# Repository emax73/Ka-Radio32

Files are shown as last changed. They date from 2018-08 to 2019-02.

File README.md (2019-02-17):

## STATE
Release 1.8 Stable

Works on any esp32 board.  
See the boards directory for a list of pre-configured boards.
- The esp32 adds the output on the internal dac or with i2s to an external dac but only mp3 stations can be played.  
Adding a vs1053 board, all stations can be played.  
Compatible with esp8266 KaRadio addons.  
- Serial or telnet commands : https://github.com/karawin/Ka-Radio32/blob/master/Interface.md

### New
A new android application is born  
  
- KaRadio Remote Control by Vassilis Serasidis on google Play.

It is an easy and fast WiFi remote control for your KaRadio or KaRadio32 hardware.  
With this android app you can select the WebRadio station you want to play, set the volume and get the station information such as Station name, Genre, Bit rate, Meta data and more.   
Found it at
https://play.google.com/store/apps/details?id=com.serasidis.karadio.rc

Thanks Vassilis.
## Added features from KaRadio
Work with i2s, internal DAC or a vs1053.  
Output mode set in Setting panel on web page of KaraDio32 :

- I2S for connection to an external DAC
- I2SMERUS to connect a merus amplifier
- DAC to use the built in DAC of the esp32
- PDM to output a PDM (Pulse Density Modulation) stream
- VS1053 to connect to a vs1053 board, I2S output of the vs1053 enabled.
- all VS1053 tones control
- AAC decoding on I2S with a wrover cpu (4mB of external psram). Mp3 only on I2S with a wroom cpu.

### Others features :

- Interfaces available on serial, telnet and html
- up to 255 editable stations.
- Handles bitrates up to 320 kbps.
- Stations can be saved and restored from html in and from a file.
- Hardware configuration file to adapt the standard delivery to all boards and addons you need.
- all configurable parameters automatically saved.
- mDNS support.
- wrover esp32 support. About 10 seconds of buffering, and soon A2DP support (sink and source)
- Time Zone Offset support.
- Latin, Cyrillic and Greek support on screen.
- 28 types of lcd or oled  B/W or Color supported.
- Programmable lcd backlight off timer.
- Touch screen if the hardware supports it.
- Two joysticks (set of two adc buttons), one for volume, one for stations.
- Two max  rotary encoders. One for volume priority, one for station change priority.
- Two max set of 3 buttons. One for volume priority, one for station change priority.
- Rotary encoder and set of buttons support included. Common functions : play/stop, volume, station change, date time display.
- ADC keyboard with 6 buttons.
- Date format DD:MM:YYYY or MM:DD:YYYY .
- Remote IR support integrated. Nec protocol only.
- Two configurable access points .
- OTA (Over The Air) update of the software.
- Uses a 40 kB (I2S), 50 kB (vs1053) or 420 Kb (wrover) queue to provide smooth playback.
- many more configurable parameters. See [Interfaces document](Interface.md )  

## Configure the hardware and IR codes
If the default configuration doesn't fit your needs, you can externally configure the software to fit your hardware and peripherals to suit your needs.  
The configuration file is to be flashed only one time. After, the standard delivery will become compatible with your hardware gpio use and peripherals configuration. A future standard OTA will automatically works for your configuration.  
See : [Hardware configuration partition](HardwareConfig.md)

## Build your own
To build your own release if you want to do some improvments, you must install the idf https://github.com/espressif/esp-idf and the toolchain.

To flash all build output, run 'make flash' or :

```
python /home/yourhome/esp/esp-idf/components/esptool_py/esptool/esptool.py \
   --chip esp32 --port com5 --baud 460800 --before default_reset \
   --after hard_reset write_flash -u --flash_mode dio \
   --flash_freq 40m --flash_size detect \
   0x1000 /home/yourhome/esp/Ka-Radio32/build/bootloader/bootloader.bin \
   0x10000 /home/yourhome/esp/Ka-Radio32/build/KaRadio32.bin \
   0x8000 /home/yourhome/esp/Ka-Radio32/build/partitions.bin
```
### GPIO Definition 
The default configuration is given below. It includes an encoder, an IR remote and a LCD or OLED.  
To add or edit GPIO definitions and add or remove some devices, you may need a hardware configuration file. Some examples are in the boards directory.  
See the file main/include/gpio.h and main/include/addon.h

```
//--------------------------------------//
// Define GPIO used in KaRadio32        //
// if no external configuration is used //
//--------------------------------------//
// Compatible ESP32 ADB
// https://www.tindie.com/products/microwavemont/esp32-audio-developing-board-esp32-adb/
// Default value, can be superseeded by the hardware partition.

// Must be HSPI or VSPI

#define KSPI VSPI_HOST

// KSPI pins of the SPI bus
//-------------------------
#define PIN_NUM_MISO GPIO_NUM_19 	// Master Input, Slave Output
#define PIN_NUM_MOSI GPIO_NUM_23	// Master Output, Slave Input   Named Data or SDA or D1 for oled
#define PIN_NUM_CLK  GPIO_NUM_18 	// Master clock  Named SCL or SCK or D0 for oled

// status led if any.
//------------------- 
// Set the right one with command sys.led
// GPIO can be changed with command sys.ledgpio("x")
#define GPIO_LED	GPIO_NUM_4		// Flashing led or Playing led

// gpio of the vs1053
//-------------------
#define PIN_NUM_XCS  GPIO_NUM_32
#define PIN_NUM_RST  GPIO_NUM_12 
#define PIN_NUM_XDCS GPIO_NUM_33
#define PIN_NUM_DREQ GPIO_NUM_34
// + KSPI pins

// Encoder knob
//-------------
#define PIN_ENC0_A   GPIO_NUM_16	//16	// 255 if encoder not used
#define PIN_ENC0_B   GPIO_NUM_17	//17	// DT
#define PIN_ENC0_BTN GPIO_NUM_5		//5// SW
#define PIN_ENC1_A   GPIO_NONE		// 255 if encoder not used
#define PIN_ENC1_B   GPIO_NONE		// DT
#define PIN_ENC1_BTN GPIO_NONE		// SW

// 3 Buttons
//-------------
#define PIN_BTN0_A   GPIO_NONE		
#define PIN_BTN0_B   GPIO_NONE		
#define PIN_BTN0_C   GPIO_NONE		
#define PIN_BTN1_A   GPIO_NONE		
#define PIN_BTN1_B   GPIO_NONE		
#define PIN_BTN1_C 	 GPIO_NONE		

// Joystick (2 buttons emulation on ADC)
//--------------------------------------
#define PIN_JOY_0	GPIO_NONE
#define PIN_JOY_1	GPIO_NONE

// I2C lcd (and rda5807 if lcd is i2c or LCD_NONE)
//------------------------------------------------
#define PIN_I2C_SCL GPIO_NUM_14
#define PIN_I2C_SDA GPIO_NUM_13
#define PIN_I2C_RST	GPIO_NUM_2		// or not used

// SPI lcd
//---------
#define PIN_LCD_CS	GPIO_NUM_13		//CS
#define PIN_LCD_A0	GPIO_NUM_14		//A0 or D/C
#define PIN_LCD_RST	GPIO_NUM_2		//Reset RES RST or not used
// KSPI pins +

// IR Signal
//-----------
#define PIN_IR_SIGNAL GPIO_NUM_21	// Remote IR source

// I2S DAC or PDM output
//-----------------------
#define PIN_I2S_LRCK GPIO_NUM_25	// or Channel1
#define PIN_I2S_BCLK GPIO_NUM_26	// or channel2
#define PIN_I2S_DATA GPIO_NUM_22	//  

// ADC for keyboard buttons
#define PIN_ADC	GPIO_NONE	//GPIO_NUM_32 TO GPIO_NUM_39 or GPIO_NONE if not used.

// LCD backlight control
#define PIN_LCD_BACKLIGHT	GPIO_NONE // the gpio to be used in custom.c 

// touch screen  T_DO is MISO, T_DIN is MOSI, T_CLK is CLk of the spi bus
#define PIN_TOUCH_CS	GPIO_NONE //Chip select T_CS

```
### LCD or oled declaration  
You can configure the kind of display used in your configuration with the command  
'sys.lcd("x")' with x:  
  
```
#define LCD_NONE		255

// Black&White
//I2C
#define LCD_I2C_SH1106		0 //128X64
#define LCD_I2C_SSD1306		1 //128X64
#define LCD_I2C_SSD1309		2 //128X64
#define LCD_I2C_SSD1325 	3 //128X64
#define LCD_I2C_SSD1306NN	4 //128X64
#define LCD_I2C_SSD1309NN	5 //128X64
#define LCD_I2C_SSD1306UN	6 //128x32

//SPI
#define LCD_SPI_SSD1306 		64 //128X32 (LCD_SPI =0x40)
#define LCD_SPI_SSD1309 		65 //128X64
#define LCD_SPI_ST7565_ZOLEN	66 //128X64
#define LCD_SPI_SSD1322_NHD		67 //256X64
#define LCD_SPI_IL3820_V2		68 //296X128
#define LCD_SPI_SSD1607			69 //200X200
#define LCD_SPI_LS013B7DH03		70 //128X128
#define LCD_SPI_SSD1306NN 		71 //128X64
#define LCD_SPI_SSD1309NN 		72 //128X64
#define LCD_SPI_ST7920 			73 //128X64

// Colors
#define LCD_SPI_ST7735			192 // 128x160  (LCD_COLOR|LCD_SPI =0xC0)
#define LCD_SPI_SSD1351			193 // 128x128
#define LCD_SPI_ILI9341			194 // 240x320
#define LCD_SPI_ILI9163			195 // 128x128
#define LCD_SPI_PCF8833			196 // 132x132
#define LCD_SPI_SSD1331			197 // 96x64
#define LCD_SPI_SEPS225			198 // 96x64
#define LCD_SPI_ST7789V			199 // 240x320
#define LCD_SPI_ST7735S			200 // 128x128
#define LCD_SPI_ST7735L			201 // 80x160
#define LCD_SPI_ST7735W			202 // 128x160 shifted 2+1
```

## First use
- If the access point of your router is not known, the webradio initialize itself as an AP. Connect the wifi of your computer to the ssid "WifiKaRadio",  
- Browse to 192.168.4.1 to display the page, got to "setting" "Wifi" and configure your ssid ap, the password if any, the wanted IP or use dhcp if you know how to retrieve the dhcp given ip (terminal or scan of the network).
- In the gateway field, enter the ip address of your router.
- Validate. The equipment restart to the new configuration. Connect your wifi to your AP and browse to the ip given in configuration.
- Congratulation, you can edit your own station list. Don't forget to save your stations list in case of problem or for new equipments.
- if the AP is already know by the esp32, the default ip is given by dhcp.
- a sample of stations list is on http://karadio.karawin.fr/WebStations.txt . Can be uploaded via the web page.        

To flash your KaRadio32 without generating it, you will need the files in the binaries directory.

The tool to use is here :  
http://espressif.com/en/support/download/other-tools  
(change the security of the installation directory to permit all)

See the image at :  
http://karadio.karawin.fr/karawin32Flash.jpg

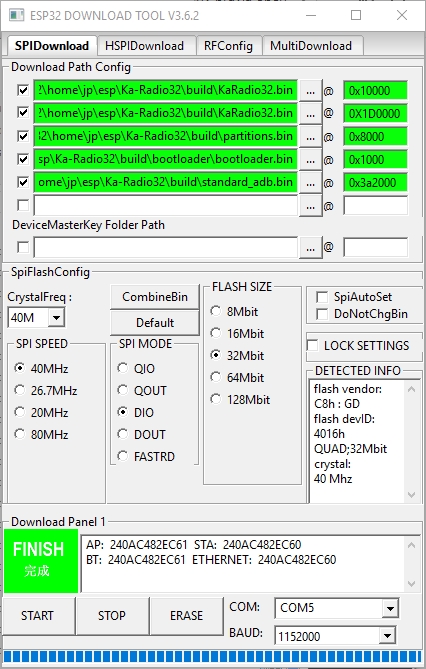
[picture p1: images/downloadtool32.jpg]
Screenshoot of download tool


### The scheme from tomasf71 : 
Just an example of a realization.  
 
Scheme

## Audio output

In the Setting panel on the webpage of KaraDio32 you can set the desired output method for audio.

For output on a simple speaker or a general analog amplifier :

- DAC to use the built in DAC of the esp32
- PDM to output a PDM (Pulse Density Modulation) stream. Wiki on PDM : https://en.wikipedia.org/wiki/Pulse-density_modulation

For output via addional I2S or VS1053 hardware :

- I2S for connection to ac external DAC
- I2SMERUS to connect a merus amplifier
- VS1053 to connect to a vs1053 board.

### Connecting a speaker, earphone or amplifier with DAC or PDM setting
You can connect the GPIO25 (left audio channel), GPIO26 (right audio channel) and Ground directly to a small loudspeaker, a simple earphone (like from an mp3 player) or the input of an analog amplifier. The quality is less perfect than using an I2S or VS1053 board, bit it is very simple hardware-wise.

Connect like this :

```
                         +------------------------------------+
ESP32-GPIO25 (left) -----+speaker/earphone/analog-amp (left)   +-----+
                         +------------------------------------+      |
                                                                     |
                         +------------------------------------+      |
ESP32-GPIO26 (right) ----+speaker/earphone/analog-amp (right  +------+
                         +------------------------------------+      |
                                                                     |
ESP32-GROUND --------------------------------------------------------+
```

### Reducing the analog output level
If the audio signal level is too high for your speaker, earphone or amplifier you can add a potentiometer to decrease the level. Connect the potentiometer like this (only pictured for 1 audio channel, for stereo you need 2 potentiometers or a stereo-potmeter.

```
                                     +--------------------------------------+
ESP32-GPIO25 (left) -------+   +-----+speaker/earphone/analog-amp (left)    +------+
                          +-+  |     +--------------------------------------+      |
                          +P+  |                                                   |
                          +o+--+                                                   |
                          +t+                                                      |
                          +++                                                      |
                           |                                                       |
ESP32-GROUND --------------+-------------------------------------------------------+
```

### Improving the audio quality with a filter
An analog DAC signal always has some noise that may cause some distortion on the audio output, especially on low volume passages in the sound. This noise can be decreased with a low-pass filter. The digital PDM signal needs allways low pass filter to convert the digital signal to an analog signal. Fortunately the speaker and earphone acts as a low pass filter, although not in a perfect way.

You can improve the analog signal with an external low-pass filter. A simple low-pass RC filter can be find on the internet, f.i. here :  
http://www.pavouk.org/hw/usbdac/en_index.html.

## Radio streams
If Karadio32 is configured to use ADC, PDM or I2S output (to an external dac) it can play audio streams in mp3 format. Other formats like AAC and WMV require too much dynamic memories and can not be played this way.

When you want to play other formats you add an external VS1053 decoder to Karadio. Details on the features of this decoder can be found here : http://www.vlsi.fi/en/products/vs1053.html

Many boards can be found at :  
https://www.aliexpress.com/wholesale?catId=0&initiative_id=SB_20180113141636&SearchText=vs1053b

## Handling streaming errors
Normally a radio station is played without interruption.

But when a connection to the server of the radio station is (temporarily) disrupted (due to internet problems or server problems) Karadio behaves as follows:

- Playing of the radio stream stops, after a short while Karadio retries to relaunch the connection to the radio stream.
- If the relaunch of the connection fails again, the webpage of Karadio then shows “invalid address” and goes into the stop state. If you have a display connected to Karadio it will then show the Date, Time and IP address.
- You can try to relaunch the connection manually by pressing “play” on the Karadio webpage, or resetting the ESP32.
- If the wifi is disconnected, the esp is rebooted.

## List of sources and components adapted for KaRadio32

- The Espressif IDF : https://github.com/espressif/esp-idf
- The Esp8266 KaRadio : https://hackaday.io/project/11570-wifi-webradio-with-esp8266-and-vs1053  
- The KaRadio addons : https://github.com/karawin/karadio-addons
- Webradio for ESP-ADB module : https://github.com/kodera2t/ESP32_OLED_webradio
- Webradio with the MP3 decoder software : https://github.com/MrBuddyCasino/ESP32_MP3_Decoder
- Black/White oled lcd library : https://github.com/olikraus/u8g2
- Color LCD library : https://github.com/olikraus/ucglib
- u8g2 Hal for esp32 : https://github.com/nkolban/esp32-snippets/tree/master/hardware/displays/U8G2
- Encoder : https://github.com/soligen2010/encoder

Encoder an Oled display

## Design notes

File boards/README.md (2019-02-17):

# BOARDS Description

This directory contains some samples of common boards found on the market.  
They are to be modified to your needs and peripheral connected.  

standard_adb.csv is the default description of the gpio used when no hardware partition is flashed.

standard_psram.bin  is the default description for a wrover cpu

standard_touch.bin  is the default description for a wroom cpu with a touch screen

lolin32pro.csv is adapted to a wrover lolin pro or ttgo board.  

ttgot8.csv, ttgotm.csv,ttgov4.csv are for the correspondant boards.

odroid.csv is for the Odroid Go device. See https://github.com/pepelnyy/KaRadio32-on-ODROID-GO

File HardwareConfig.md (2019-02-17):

# Hardware configuration partition

Version 1.5 and up of KaRadio32 allows you to configure gpio's and two custom IR keys per action.  
This allows you to take advantage of the standard software even if your port configuration and/or your remote control are not the same.  
The configuration must be specified in a csv file.  
A template is given by the pattern.csv file
The default configuration of the current software is in the standard_adb.csv file.  
A csv file is interpreted by an utility to generate a bin file that must be flashed at address 0x3a2000 only one time per esp32

---------------
1/ Prerequisite
---------------
Toolchain Setup
--------------------
The quick setup is to download the Windows all-in-one toolchain & MSYS2 zip file from dl.espressif.com:

https://dl.espressif.com/.../esp32_win32_msys2...

- Unzip the zip file to C:\ (or some other location, but this guide assumes C:\) and it will create an msys32 directory with a pre-prepared environment.
- Open a MSYS2 MINGW32 terminal window by running C:\msys32\mingw32.exe. Create a directory named "esp" that is a default location to develop ESP32 applications. To do so, run the following shell command: mkdir -p ~/esp
- Type : cd ~/esp to move the newly created directory. If there are no error messages you are done with this step.
- Type : git clone -b v3.1.2 --recursive https://github.com/espressif/esp-idf.git
- Create a new script file in C:/msys32/etc/profile.d/ directory. Name it export_idf_path.sh
Identify the path to ESP-IDF directory. It is specific to your system configuration and may look something like C:\msys32\home\"your-user-name"\esp\esp-idf
Add this to the above created script file: export IDF_PATH="C:/msys32/home/"your-user-name/esp/esp-idf"
Save the script file.
- Close MSYS2 window and open it again. Check if IDF_PATH is set, by typing: printenv IDF_PATH
The path previously entered in the script file should be printed out.
- Type : pip install --upgrade setuptools  
- Type : python -m pip install --upgrade pip
- Type : pip install future
- Type : pacman -S mingw-w64-i686-python2-cryptography
- Type : pip install cryptography
- Place the Ka-Radio32-master files in "your-user-name"/esp folder. Find it at https://github.com/karawin/Ka-Radio32
---
  
Second  make sure you have an updated partitions.bin file.  
Find it at "your-user-name"/esp/Ka-Radio32/tree/master/binaries  
This file contains the system partitions:
```
$ make partition_table
Toolchain path: /opt/xtensa-esp32-elf/bin/xtensa-esp32-elf-gcc
Toolchain version: crosstool-ng-1.22.0-80-g6c4433a5
Compiler version: 5.2.0
Python requirements from C:/msys32/home/jp/esp/esp-idf/requirements.txt are satisfied.
Partition table binary generated. Contents:
*******************************************************************************
# Espressif ESP32 Partition Table
# Name, Type, SubType, Offset, Size, Flags
nvs,data,nvs,0x9000,16K,
otadata,data,ota,0xd000,8K,
phy_init,data,phy,0xf000,4K,
ota_0,app,ota_0,0x10000,1792K,
ota_1,app,ota_1,0x1d0000,1792K,
device,64,0,0x390000,4K,
stations,65,0,0x391000,64K,
device1,66,0,0x3a1000,4K,
hardware,data,nvs,0x3a2000,8K,
*******************************************************************************
Partition flashing command:
python /home/jp/esp/esp-idf/components/esptool_py/esptool/esptool.py --chip esp32 --port com5 --baud 460800 --before default_reset --after hard_reset write_flash 0x8000 /home/jp/esp/Ka-Radio32/build/partitions.bin
************************************************ *****************************
```
Compared to an old version, it adds the declaration of the partition "hardware" which interests us.

Rename the pattern.csv file with the name of your c
ard, for example lolin32.csv  
Beware: not comment line or empty line allowed in a csv file.

#### WARNING:
The declaration of gpio's is a not so easy task.  
Any error results in an incorrect start of the software.  
If the software does not start properly, please check your values.  
A common mistake is to declare the same number for two functions.  
See the log on the serial interface.

------------------------------------
2/ Definition of gpio's and options
------------------------------------
Edit the csv file to enter your gpio and options definitions.  
See gpio.h for the default values if missing in the csv file.  
Only modify the lines beginning with P_ or O_ by modifying only the last number.  
for example:  
P_MISO, data,u8,19  
Change 19 to the desired number.  
Do this for all P_ and O_lines.  
Never change the string "P_XXXX, data,u8,"  
A value base 10 is mandatory for each P_.  

## GPIO
Definition of the lines in csv  
- **SPI Bus:**  
K_SPI		Select the used spi : 1: HSPI, 2: VSPI  
P_MISO		Master Input, Slave Output    
P_MOSI		Master Output, Slave Input   Named Data or SDA or D1 for oled  
P_CLK		Master clock  Named SCL or SCK or D0 for oled  
- **VS1053B:**  
P_XCS			XCS  
P_RST			RST  
P_XDCS			XDCS  
P_DREQ			P_DREQ  
- **ENCODERS 0 & 1:**  
P_ENC0_A			pin A clk  
P_ENC0_B			pin B Data  
P_ENC0_BTN			pin SW  
P_ENC1_A			pin A clk  
P_ENC1_B			pin B Data  
P_ENC1_BTN			pin SW  
- **BUTTONS PANEL 0 & 1** of three buttons (switch to gnd):  
P_BTN0_A		click:start/stop, double click:toggle, help: station  
P_BTN0_B		click: +  
P_BTN0_C		click: -  
P_BTN1_A		start/stop, toggle, volume  
P_BTN1_B		+  
P_BTN1_C		-  
- **JOYSTICK 0 & 1**  
P_JOY_0			Volume control  	
P_JOY_1		
- **Bus I2C (Oled & Lcd):**  
P_I2C_SCL		SCL or SCK  
P_I2C_SDA		SDA  
P_I2C_RST		RST if any  
- **LCD on SPI bus:**  
P_LCD_CS		CS  
P_LCD_A0		A0 or D/C or DC  
P_LCD_RST		RST or RES  
- **Infrared remote:**  
P_IR_SIGNAL		ir Y Signal  
- **I2S bus:**  
P_I2S_LRCK		LRCK  
P_I2S_BCLK		BCLK  
P_I2S_DATA		DATA  
- **ADC keyboard:**  
P_ADC_KBD			gpio32 to 39  or 255 if not used. 
- **LCD Backlight:**   
P_BACKLIGHT		GPIO of the hardware device.
- **TOUCH SCREEN:**  
P_TOUCH_CS		GPIO of the t_cs pin of the touch or 255 if no screen  
  Other pins are t_clk, t_din, t_do respectively the spi clk, mosi, miso. T_irq is not used.  
- **LED GPIO**  
P_LED_GPIO		GPIO of the status led  

## OPTIONS
- **LCD CONTROL**  
P_LCD_TYPE		Type of lcd (see [addon.h](https://github.com/karawin/Ka-Radio32/blob/master/main/include/addon.h) file).  
P_LCD_ROTA		Control the rotation of the LCD, 0 no rotation, 1: rotation.  
O_LCD_OUT 		The tempo to light off the screen in seconds. 0 is no tempo.   
O_DDMM_FLAG		The format of the date to display 0:MMDD, 1:DDMM.  
-------------------
## Special cases:
-------------------
### GPIO
- GPIOs 34 to 39 are input only pins.  
These pins don’t have internal pull-ups or pull-down resistors.  
They can’t be used as outputs, so use these pins only as inputs or ADC usage.  
- Digital to Analog Converter (DAC)  
There are 2 x 8 bits DAC channels on the ESP32 to convert digital signals into analog voltage signal outputs.  
These are the DAC channels:  
-    DAC1 (GPIO25)  
-    DAC2 (GPIO26)
### SPI bus

K_SPI,data,u8,2  
- 1 is the spi HSPI_HOST  
- 2 is the spi VSPI_HOST (default)  
   The spi bus is initialized in any case. It used for the vs1053 and/or the LCD if needed.  
   Prefered gpio for the spi bus (IOMUX):  
   HSPI: SCLK=14, MISO=12, MOSI=13  
   VSPI: SCLK=18, MISO=19, MOSI=23  

### Encoders

Two encoders maximun are supported, each with different actions:  
Encoder0: the volume control and stations change when pushed and held,  
Encoder1: the station control and volume change when pushed and held.  

If P_ENC0_A = 255 the encoder (P_ENC0_A, P_ENC0_B, P_ENC0_BTN) is disabled (not used, the gpio's may be reused elsewhere).    
If P_ENC1_A = 255 the encoder (P_ENC1_A, P_ENC1_B, P_ENC1_BTN) is disabled (not used, the gpio's may be reused elsewhere).  
If If P_ENC0_A is not 255 and P_ENC0_BTN = 255, the push button is disabled.  
If If P_ENC1_A is not 255 and P_ENC1_BTN = 255, the push button is disabled.  

### Buttons
Two set of three buttons can be configured in place or with encoder(s). The only limit is the available gpio's.  
Each set has functions equivalent to Encoder0 and Encoder1:  
click on button A: Start/Stop playing  
click on button B and C: volume down and up for set 0 (P_BTN0), Station down and up for set 1 (P_BTN1)  
held on button A: click on button B and C: volume down and up for set 1 (P_BTN1), Station down and up for set 0 (P_BTN0)  

If a set is not used, P_BTNx_A must be set to 255. In this case P_BTNx_B P_BTNx_C are disabled too.

### Joystick
A joystick is a set of two buttons but both cannot be pushed at the same time.  
The GPIO must be an ADC one, i.e gpio32 to 39  or 255 if not used.   
Joystick 0  controls the volume,  
Joystick 1 controls the station choice.  
Botton 0 is 3.3 V  
Button 1 is 3.3/2 V  
An example of joystick:  
Screenshoot of joystick

### I2C
If I2C is not used (ie no lcd or spi lcd) the gpio of the i2C can be reused elsewhere.  
To disable I2C even a I2C LCD is used: P_I2S_LRCK	and/or P_I2S_BCLK	must be set to 255  

### VS1053b
If not used P_XCS must be set to 255. Gpio of P_RST P_XDCS P_DREQ may be reused elsewhere.  

### IR
If IR remote control is not used P_IR_SIGNAL must be set to 255

### ADC keyboard
If the ADC keyboard is missing, set P_ADC  to 255.  
GPIO pin must be gpio32 to 39  or 255 if not used.   
Compatible with https://github.com/karawin/Ka-Radio/blob/master/Hardware/controles.pdf and the one found at https://www.drive2.ru/b/487463808323813881/  
The stop button is replaced with "Toggle Time/Infos" and "start replaced with "Start/Stop"  
The ESP32 ADC can be sensitive to noise leading to large discrepancies in ADC readings. To minimize noise, users may connect a 0.1uF capacitor to the ADC input pad in use

### Lcd backlight
Thanks to Vadim Polyakovsky:
> A small optional schematics update which allows to switch LCD backlight on and off in case of battery powered KaRadio. The switching off timeout in x sec could be defined by sys.lcdout("x") terminal command. The display and its' backlight will wake up automatically in case of new meta, encoder or IR event. This way the battery life on one charge will be extended. Obviously not needed for OLED displays and wall plug power socket operation. A software support is done by Jean-Pierre in the new custom.c file. A GPIO number could be chosen among not used ones and defined respectively. Enjoy!
 
This external device turns off the LCD backlight in addition to the screen clear.    
Usefull if a battery is used.  
If the hardware device is missing, set it to 255

Screenshoot of backlight  

### TOUCH SCREEN
P_TOUCH_CS  of the t_cs pin of the touch or 255 if no screen.  
Other pins are t_clk, t_din, t_do respectively the spi clk, mosi, miso. T_irq is not used.  
The screen must be calibrated with the command sys.cali[brate]  
The screen is divided in 5 zones:  
- Center: Start/Stop
- Top: Volume+
- Bottom: Volume-
- Left: Station-
- Bottom: Station+

### OPTIONS
If any options value is 255, the values defined by sys. command are unchanged.  
If a sys. command changes the value in csv, the internal flashed bin of the csv is updated.  
As long  the original bin is not flashed again, the internal value apply. 

---------------------
3/ IR key definitions
---------------------
If you use a remote control with different codes from the default ones, you can give your codes by key.
Two codes per key are possible:

For example for the K_OK key  
K_OK, data, string, 0xFF0040 0xFF0040  
or  
K_OK, data, string, 0xFF0040  
if you only have one code per key.  
or  
K_OK, data, string,  
if no code is given for the OK key  

Never change "K_XXXX,data,string,"  

Reminder: to see the code of a key on your remote control, change the log level to sys.logi  
Press a key and see the log. You will see something like that:  
I (1204396) addon: IR event: Channel: 0, ADDR: ff00, CMD: bf40 = FF0040, REPEAT: 0  
Where FF0040 is the 0xFF0040 code needed.  
```
The keys and actions are:
K_UP  		Change to next Station 
K_LEFT		Volume Down -5
K_OK		Toggle play/Stop
K_RIGHT		Volume up +5
K_DOWN		Change to previous station
K_0			Enter number of the wanted station
K_1			Enter number of the wanted station
K_2			Enter number of the wanted station
K_3			Enter number of the wanted station
K_4			Enter number of the wanted station
K_5			Enter number of the wanted station
K_6			Enter number of the wanted station
K_7			Enter number of the wanted station
K_8			Enter number of the wanted station
K_9			Enter number of the wanted station
K_STAR		Play
K_DIESE		Stop
K_INFO		Toggle time/info display
```
No comment is allowed in this csv file.  
Save the csv file.

------------------------
4/ Generating the bin
------------------------
Some samples are in the boards directory.   

Build the bin file
------------------
1. Place the Ka-Radio32-master files in "your-user-name"/esp folder
2. Place your modified csv file in the Ka-Radio32-master/boards folder

3. Return to the msys32 window and navigate to the Ka-Radio32-master/boards folder

4. Start the command : ./nvs_partition_generator.sh yourname[.csv] to generate build/yourname.bin

Result :   
MINGW32 ~/esp/Ka-Radio32-master/boards  
$ ./nvs_partition_generator.sh modified_adb  
python ./nvs_partition_gen.py modified_adb.csv build/modified_adb.bin 0x2000  
done  

------------
5/ Flash the bin
------------
With ESP DOWNLOAD TOOL   
Screenshoot of download tool

or esptool.py command at address 0x3a2000  

It seems that there is a problem with this ESP DOWNLOAD TOOL for flashing the bin alone.  
In case of problem, flash it with another bin (bootloader.bin or KaRadio32.bin) 
 
This binary is to flash one time and on each modification of the csv.

Now you can enjoy the standart OTA. No needs to generate your own KaRadio32.bin.

JP 2018

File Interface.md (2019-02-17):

# Interfaces of KaRadio and KaRadio32
____________________________________

## HTML interface for the Wifi Webradio
Any browser or wget can be used to send basic commands to the webradio.  
A command format is http://yourip/?command[&command]  
If a command return some informations, it must be the last of the list or alone.

## Commands:  
- version		: return 'Release: x.x, Revision: x'  
- infos			: return   
				vol: 46						:the current volume  
				num: 240						:the current station number  
				stn: Hotmix 80					:the name of the current station  
				tit: BANANARAMA - Venus 		:the title of the son playing  
				sts: 1							:the state of the player: 0 stopped, 1:   playing.
- list=xxx		: return the name of the station xxx (0 to 254)				
- stop			: stop playing the current station.
- start			: start playing the current station.
- next			: play the next station
- prev			: play the previous station
- play=xxx		: with xxx from 0 to 254  play the station xxx
- volume=xxx		: with xxx from 0 to 254  change the volume to xxx
- uart			: uart baudrate at 115200 not saved on next reset
- instant="http://your url" : instant play a site  
Example: http://192.168.1.253/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"  
the url must begin with http:// and be surrounded by " and no space char allowed.

Volume may be combined with other command.  
Example: 192.168.1.253/?volume=50&play=128&infos

Reminder: the url without parameter is the full web interface.

-------------------------------------------------
## Serial ot telnet interface for the Wifi Webradio

The serial inteface can be used to receive events from the webradio and to send commands to it.  
The telnet interface is reached by the port 23.  
The serial interface adds the logs output of the tasks.  

Example of indications received: 
```
##CLI.STOPPED# from playStationInt
##CLI.NAMESET#: 88 Public Domain Classical - Swiss Internet Radio
##CLI.URLSET#: 82.197.165.137
##CLI.PATHSET#: /
##CLI.PORTSET#: 80
##CLI.OVOLSET#: 0
##CLI.VOL#: 110
##CLI.ICY0#: Public Domain Classical - Swiss Internet Radio - Shoutcast Streaming Technology by www.init7.net
##CLI.ICY1#: <BR>This stream requires <a href="http://www.winamp.com/">Winamp</a><BR>
##CLI.ICY2#: SHOUTcast Distributed Network Audio Server/Linux v1.9.8<BR>
##CLI.ICY3#: http://publicdomainproject.org
##CLI.ICY4#: Classical
##CLI.ICY5#: 128
##CLI.META#: Felix Mendelssohn-Bartholdy - String Quartet in E flat major Op. 44 No.3: 4. Molto allegro con fuoco
##CLI.PLAYING#
##CLI.STOPPED# from playStationInt
##CLI.NAMESET#: 92 ALBUMROCK.MIAMI
##CLI.URLSET#: uk4.internet-radio.com
##CLI.PATHSET#: /
##CLI.PORTSET#: 8081
##CLI.OVOLSET#: 0
##CLI.VOL#: 110
##CLI.ICY0#: ALBUMROCK.MIAMI
##CLI.ICY1#: <BR>This stream requires <a href="http://www.winamp.com/">Winamp</a><BR>
##CLI.ICY2#: SHOUTcast Distributed Network Audio Server/Linux v1.9.8<BR>
##CLI.ICY3#: www.AlbumRock.Miami
##CLI.ICY4#: Classic  Rock 60s 70s 80s Miaimi Florida  Album Rock
##CLI.ICY5#: 128
##CLI.META#: The Who - Eminence Front 
##CLI.PLAYING#
#CLI.LIST#
#CLI.LISTINFO#:   2: RTL2, streaming.radio.rtl.fr:80/rtl2-1-44-128.m3u
##CLI.LIST#
(cli.info) typed
##CLI.NAMESET#: 92 ALBUMROCK.MIAMI
##CLI.ICY0#: ALBUMROCK.MIAMI
##CLI.ICY1#: <BR>This stream requires <a href="http://www.winamp.com/">Winamp</a><BR>
##CLI.ICY2#: SHOUTcast Distributed Network Audio Server/Linux v1.9.8<BR>
##CLI.ICY3#: www.AlbumRock.Miami
##CLI.ICY4#: Classic  Rock 60s 70s 80s Miaimi Florida  Album Rock
##CLI.ICY5#: 128
##CLI.ICY6#: 
##CLI.ICY7#: 
##CLI.META#: The Who - Eminence Front
##CLI.VOL#: 108
##CLI.PLAYING#
##CLI.META#: The Beatles - Mother Nature's Son 
##SYS.TZO#: 1
##SYS.DATE#: 2017-04-13T22:47:44+01:00
```

with ICYx: 0:"icy-name:", 1:"icy-notice1:", 2:"icy-notice2:",  3:"icy-url:", 4:"icy-genre:", 5:"icy-br:", 6:"icy-description:", 7:"ice-audio-info:"  
Some other informations may be printed for debug purpose, but usefull events always start with ##

## Commands:

### Wifi related commands
```
wifi.list			: give the list of received SSID
wifi.con			: Display the AP1 and AP2 SSID
wifi.con("ssid","password")	: Record the given AP ssid with password in AP1 for next reboot
wifi.discon			: disconnect the current ssid
wifi.station		: the current ssid and password
wifi.status			: give #WIFI.STATUS#			start of the answer
				5						the connection state
				192.168.1.40			the current ip
				255.255.255.0			the network mask
				192.168.1.70			the network gateway
				##WIFI.STATUS#			end of the answer
wifi.rssi			: print the current rssi (reception level)
```				

### Station Client commands
```
// instant play
cli.url("url")		: the name or ip of the station to instant play
cli.path("/path")	: the path of the station to instant play
cli.port("xxxx")	: the port number of the station to instant play
cli.instant:		: play the instant station
// Stations play					
cli.start			: start to play the current station
cli.play("xxx")		: play the xxx recorded station in the list (0 = stop)
cli.prev (or cli.previous)	: select the previous station in the list and play it
cli.next			: select the next station in the list and play it
// Station stop
cli.stop			: stop the playing station or instant
// station list
cli.list			: list all recorded stations
cli.list("x")		: list only one of the recorded stations. Answer with #CLI.LISTINFO#: followed by infos
// volume commands
cli.vol("xxx")		: set the volume to xxx with xxx from 0 to 254 (max volume)
cli.vol				: ask for  the current volume. respond with ##CLI.VOL# xxx
cli.vol-			: Decrement the volume by 10
cli.vol+			: Increment the volume by 10
Every vol command from uart or web or browser respond with ##CLI.VOL#: xxx
// Client information
cli.info			: Respond with nameset, all icy, meta, volume and stae playing or stopped. Used to refresh the lcd informations
					: see Example of indications received
```
### System commands
```
sys.uart("x")	: Change the baudrate of the uart on the next reset. 
			Valid x are: 1200, 2400, 4800, 9600, 14400, 19200, 28800, 38400, 57600, 76880, 115200, 230400	
sys.i2s			: Display the current I2S speed			
sys.i2s("x")	: Change and record the I2S clock speed of the vs1053 GPIO5 MCLK for the i2s interface to external dac. 
				: 0=48kHz, 1=96kHz, 2=192kHz, other equal 0
sys.erase		: erase all recorded configuration and stations. Dangerous command.
sys.heap		: show the ram heap size
sys.update		: start an OTA (On The Air) update of the software
sys.prerelease	: start an OTA of the prerelease for test purpose.
sys.boot		: reboot the webradio.
sys.patch("x")	: Change the status of the vs1053 patch at power on. 
				  0 = Patch will not be loaded, 1 or up = Patch will be loaded (default) at power On
sys.patch		: Display the vs1053 patch status
sys.led("x")	: Change the led indication: 
				  1 = Led is in Play mode (lighted when a station is playing), 0 = Led is in Blink mode (default)
sys.led			: Display the led indication status
sys.tzo("xx")	: Set the timezone offset of your country.
sys.tzo			: Display the timezone offset
sys.date		: Send a ntp request and Display the current locale time
				: Format ISO-8601 local time   https://www.w3.org/TR/NOTE-datetime
				: YYYY-MM-DDThh:mm:ssTZD (eg 2017-07-16T19:20:30+01:00)
sys.adc			: Read the current value of the adc input. (Not for KaRadio32)
sys.log			: Do nothing. Used for debug of the addon.	
sys.version		: Display the release and Revision of KaraDio
sys.host		: display the hostname for mDNS			
sys.host("your hostname"): change and display the hostname for mDNS
```
### Other
```
<enter> will display 
#INFO:""#

help			: list the available commands.
```
A command error display:
```
##CMD_ERROR#
```
### Extension for KaRadio32 only:
```
sys.dlog		: Display the current log level
sys.logx		: Set log level to x with x=n for none, v for verbose, d for debug, i for info, w for warning, e for error
sys.lcdout		: Display the timer to switch off the lcd. 0= no timer
sys.lcdout("x")	: Timer in seconds to switch off the lcd. 0= no timer
sys.lcd			: Display the current lcd type
sys.lcd("x")	: Change the lcd type to x on next reset
sys.ledgpio		: Display the default Led GPIO
sys.ledgpio("x"): Change the default Led GPIO (4) to x
sys.ddmm: display the date format
sys.ddmm("x"): Change the date format. 0:MMDD, 1:DDMM
sys.rotat: display the lcd rotation option
sys.rotat("x"): Change and display the lcd rotation option (reset needed). 0:no rotation, 1: rotation
sys.henc0 or sys.henc1: Display the current step setting for the encoder. Normal= 4 steps/notch, Half: 2 steps/notch
sys.henc0("x") with x=0 Normal, x=1 Half
sys.henc1("x") with x=0 Normal, x=1 Half
sys.cali[brate]: start a touch screen calibration
```

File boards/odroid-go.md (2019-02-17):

The odroid Gp board is fully described in the csv file.
To have some informations,  see 
https://github.com/pepelnyy/Ka-Radio32-on-ODROID-GO

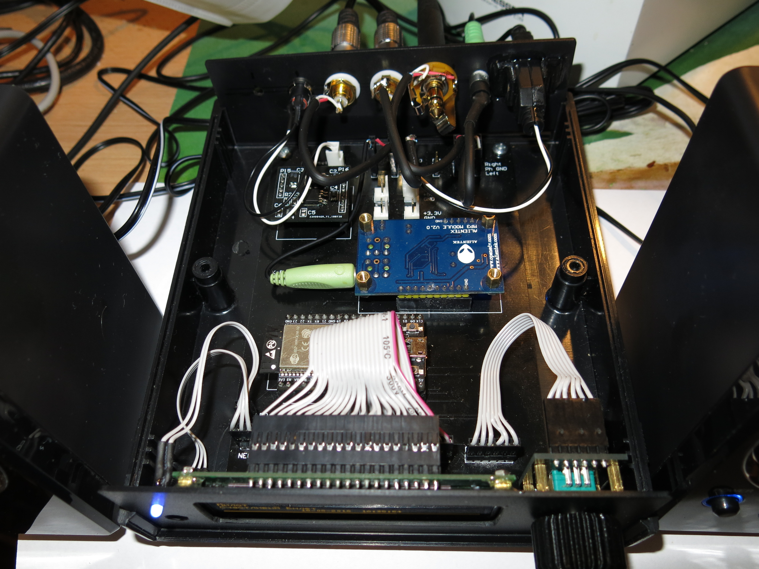
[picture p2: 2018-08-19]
photos/03.KaRadio32.open.case.jpg

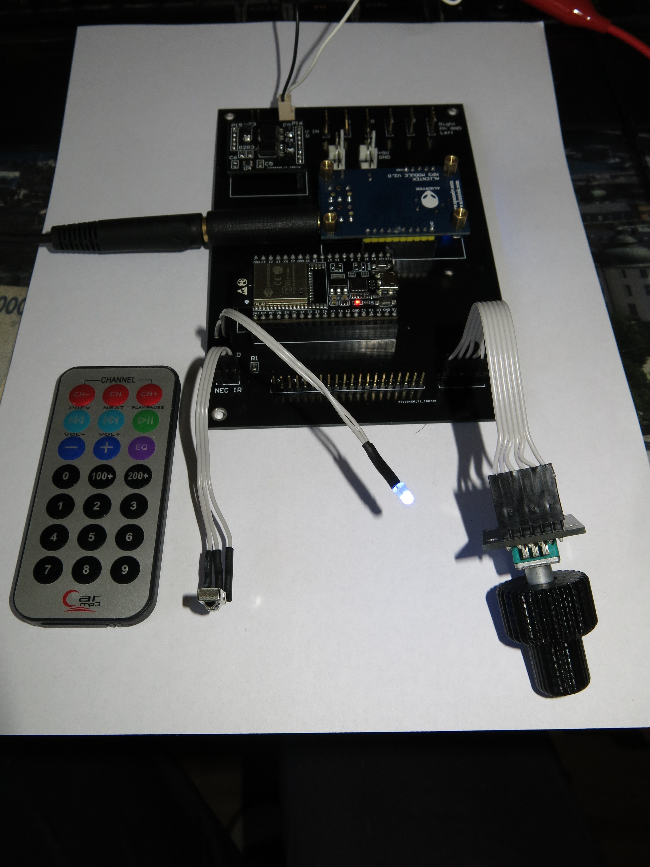
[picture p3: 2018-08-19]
photos/02.KaRadio32.pcb.jpg

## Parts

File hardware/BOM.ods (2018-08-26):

KaRadio32 cost
ESP32 DevKit | ESP-32 Mini Core Dev. Board, ESP32-DevKitC, V4 |  |  | 1 | 8,16 | 8,16 | www.electrodragon.com | http://www.electrodragon.com/product/esp32-devkitc/
VS1053B Module | ALIENTEK VS1053 module MP3 player audio decoder Module VS1053 MP3 Module |  | Alientek | 1 | 11,475 | 11,475 | www.aliexpress.com | https://www.aliexpress.com/item/Free-Shipping-ALIENTEK-VS1053-module-MP3-player-audio-decoder-Module-VS1053-MP3-Module/32506214313.html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
Case 178 mm x 152 mm x 51 mm 1598CBK Hammond Manufacturing | https://www.hammfg.com/part/1598CBK?referer=1199 |  |  | 1 | 13,94 | 13,94 | eu.mouser.com | https://eu.mouser.com/ProductDetail/Hammond-Manufacturing/1598CBK
Plastic End Panels 1598PLCBK |  |  |  | 1 | 1,86 | 1,86 | eu.mouser.com | https://eu.mouser.com/ProductDetail/Hammond-Manufacturing/1598PLCBK
PCB Screws | 1598ATS100 |  |  | 100 | 0,0868 | 8,68 | eu.mouser.com | https://eu.mouser.com/ProductDetail/Hammond-Manufacturing/1598ATS100
PCB |  |  | JLCPCB | 1 | 12,27 | 12,27 | www.jlcpcb.com | https://www.jlcpcb.com/
OLED Displays & Accessories OLED 256 x 64 Yellow 89.2 x 44.0 x 6.0 | NHD-3.12-25664UCY2 |  | Newhaven Display | 1 | 27,27 | 27,27 | eu.mouser.com | https://eu.mouser.com/ProductDetail/Newhaven-Display/NHD-312-25664UCY2
Dual Encoder | EC11EBB24C03 |  | Alps | 1 | 26,36 | 26,36 | eu.mouser.com | https://eu.mouser.com/ProductDetail/ALPS/EC11EBB24C03
Speakers Swen 247 |  |  |  | 1 | 8,05 | 8,05 | www.aio.lv | https://aio.lv/ru/komputernye-komponenty-monitory-periferia-po/kolonki/sven-247-akusticeskaa-sistema-20-dla-komputera-4w-cernye:92984
LDO 3.3V PPAK | LF33CPT-TRY | Linear Voltage Regulators VLDV Reg Inhibit 0.45V 50uA 500mA |  | 1 | 0,765 | 0,765 | eu.mouser.com | https://eu.mouser.com/ProductDetail/STMicroelectronics/LF33CPT-TRY
LDO 5V PPAK | LF50CPT-TRY |  |  | 1 | 1 | 1 | eu.mouser.com | https://eu.mouser.com/ProductDetail/STMicroelectronics/LF50CPT-TRY
Tantal 100uF x 10V | TMCMB1A107MTRF |  |  | 3 | 0,425 | 1,275 | eu.mouser.com | http://eu.mouser.com/ProductDetail/Vishay/TMCMB1A107MTRF/
Tantalum Capacitors - Solid SMD 470uF 10volts | 293D477X9010E2TE3 |  |  | 5 | 1,77 | 8,85 | eu.mouser.com | https://eu.mouser.com/ProductDetail/Vishay-Sprague/293D477X9010E2TE3
Power Supply | Universal (7.5V), 1A |  |  | 1 | 5 | 5 | www.ebay.com
IR Receiver | TSOP4438 - Infrared Receiver, Remote Control, 38 kHz, 45m, 45 °, 5.5 V, 2.5 V, -25 °C | TSOP4438 |  | 1 | 0,439 | 0,439 | lv.farnell.com | http://lv.farnell.com/vishay/tsop4438/ir-receiver-small-agc4-38khz/dp/2251381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
Audio Connector 3.5mm |  |  |  | 1 | 0,24 | 0,24 | aliexpress.com | https://ru.aliexpress.com/item/5PCS-LOT-PJ392-3-5mm-Stereo-Female-Sockect-Jack-with-Screw-3-5-Audio-Headphone-Connector/32828608647.html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
Audio Connector 6.3mm |  |  |  | 1 | 0,415 | 0,415 | aliexpress.com | https://ru.aliexpress.com/item/10Pcs-lot-1-4-6-35mm-Stereo-Socket-Jack-Female-Connector-Panel-Mount-Solder/32777665022.html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
RCA Connectors |  |  |  | 2 | 0,1705 | 0,341 | aliexpress.com | https://ru.aliexpress.com/item/10pcs-RCA-Female-Connector-Socket-Adapter-Plug-For-3-5mm-Audio-Plug-AV-Plug-Gold-Black/32815822825.html
USB Type-A Female |  |  |  | 1 | 0,124 | 0,124 | www.ebay.com | https://www.ebay.com/itm/10Pcs-USB2-0-Type-A-Plug-4-pin-female-Adapter-Connector-jack-Black-Plastic-Cover/272041592263
Reset Button |  |  |  | 1 | 0,228 | 0,228 | www.ebay.com | https://www.ebay.com/itm/10pcs-5mm-Momentary-Push-button-Switch-Press-the-reset-switch-Normally-Open-HT/112981659318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
DC Power Connectors Power Jacks 5.7x2.5mm | PJ-005B |  | CUI | 1 | 1,92 | 1,92 | eu.mouser.com | http://eu.mouser.com/ProductDetail/CUI/PJ-005B/
IR Remote NEC |  |  |  | 1 | 1,28 | 1,28 | www.ebay.com | https://www.ebay.com/itm/HX1838-VS1838-NEC-Infrared-IR-Wireless-Remote-Control-Sensor-Module-For-arduino/400529215865
 |  |  |  |  |  | 0
 |  |  |  |  |  | 0
 |  |  |  |  |  | 0
 |  |  |  |  |  | 0
 |  |  |  |  |  | 0
 |  |  |  |  |  | 0
 |  |  |  |  |  | 0
 |  |  |  |  |  | 0
 |  |  |  |  |  | 0
 |  |  |  |  |  | 0
 |  |  |  |  |  | 0
 |  |  |  |  |  | 0
 |  |  |  |  | Sum | 139,942 | + VAT | 169,32982

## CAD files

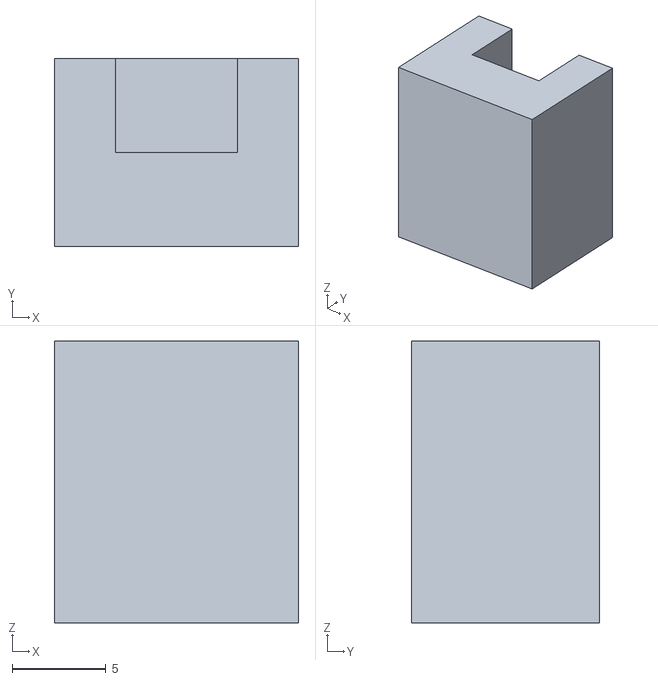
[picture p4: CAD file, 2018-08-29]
3dprint/IR.TSO4438.stl
13.0 x 10.0 x 15.0

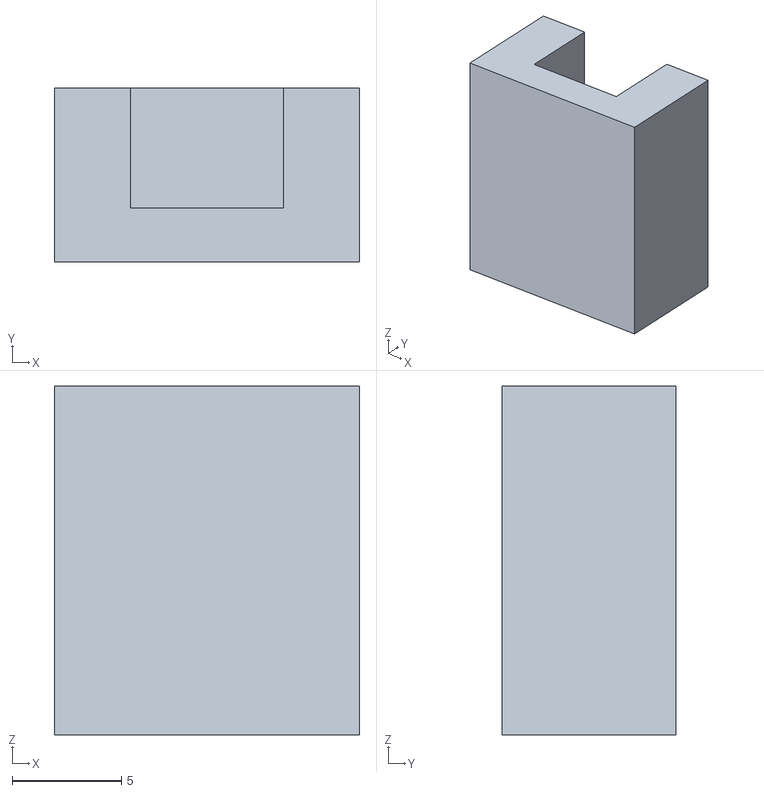
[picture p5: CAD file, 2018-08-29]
3dprint/IR.stl
14.0 x 8.00 x 16.0

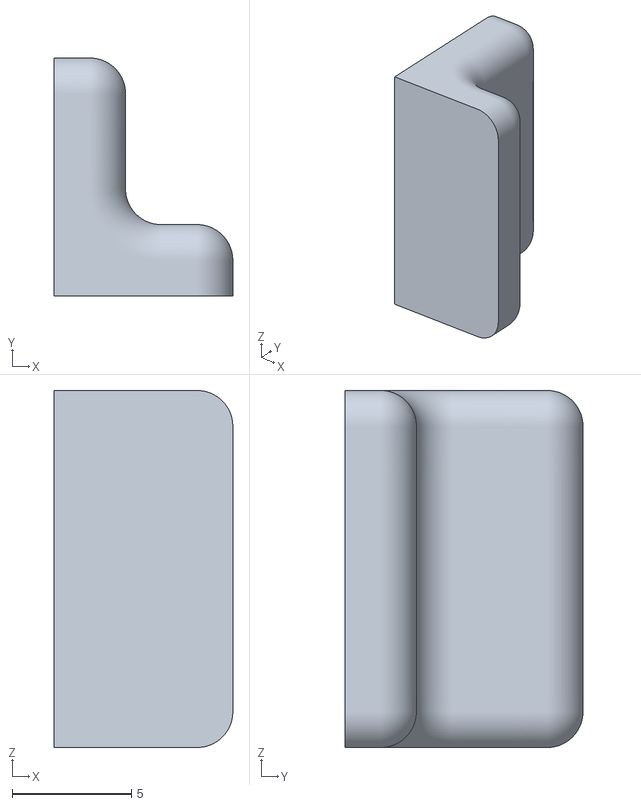
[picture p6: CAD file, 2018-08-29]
3dprint/USB.Holder.stl
7.51 x 10.0 x 15.0

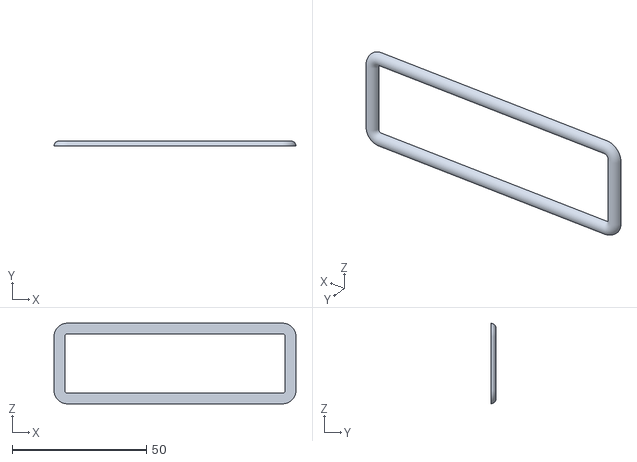
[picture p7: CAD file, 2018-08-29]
3dprint/OLED.glass.bezel.stl
90.0 x 2.00 x 30.0

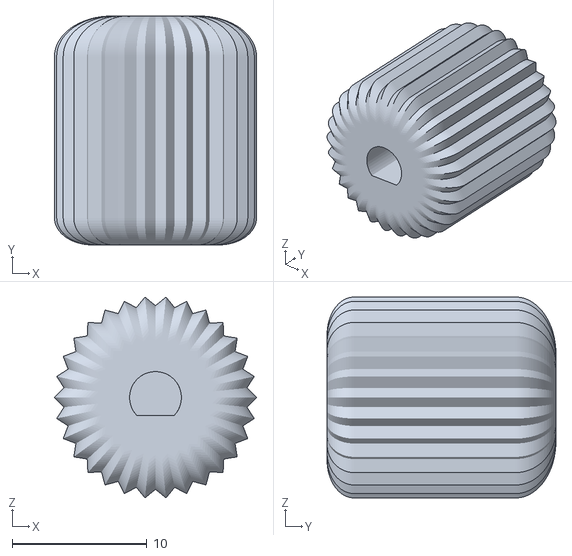
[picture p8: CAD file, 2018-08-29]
3dprint/Knob1.2.stl
15.0 x 17.0 x 14.9

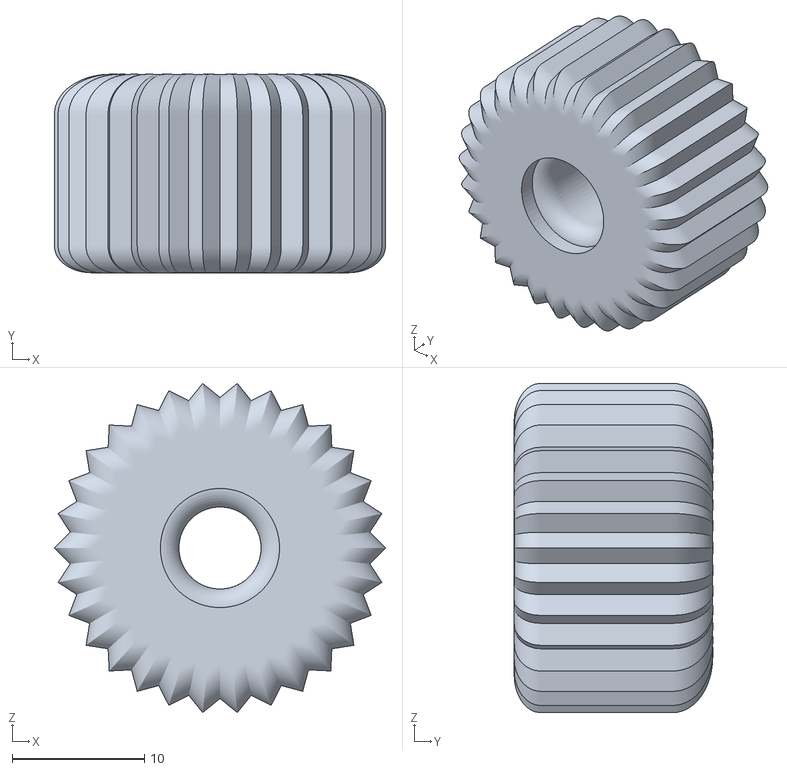
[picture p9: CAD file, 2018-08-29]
3dprint/Knob2.2.stl
25.0 x 15.0 x 24.9

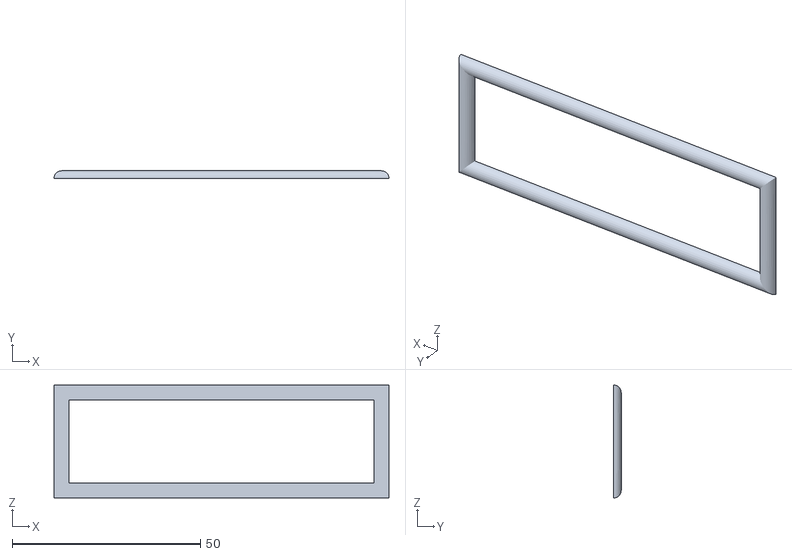
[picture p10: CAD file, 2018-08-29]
3dprint/OLED.bezel.stl
89.0 x 2.00 x 30.0

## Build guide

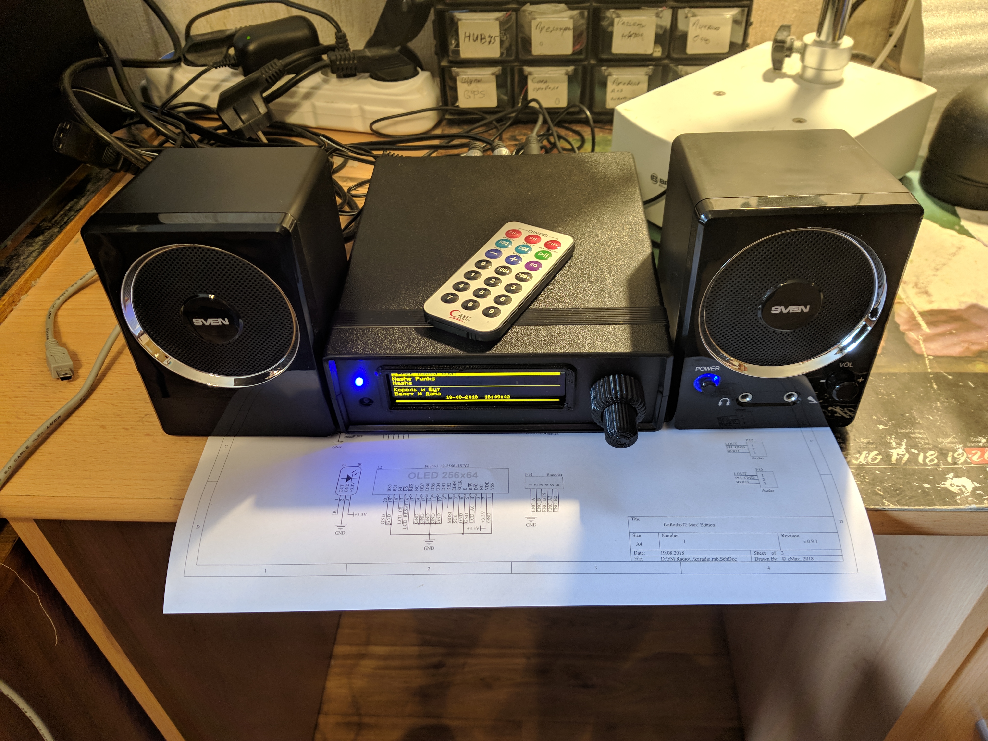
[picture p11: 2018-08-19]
photos/01.KaRadio32.assembled.jpg

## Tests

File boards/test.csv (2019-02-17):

key | type | encoding | value
gpio_space | namespace
K_SPI | data | u8 | 1
P_MISO | data | u8 | 12
P_MOSI | data | u8 | 13
P_CLK | data | u8 | 14
P_XCS | data | u8 | 255
P_RST | data | u8 | 12
P_XDCS | data | u8 | 33
P_DREQ | data | u8 | 34
P_ENC0_A | data | u8 | 18
P_ENC0_B | data | u8 | 19
P_ENC0_BTN | data | u8 | 4
P_ENC1_A | data | u8 | 255
P_ENC1_B | data | u8 | 17
P_ENC1_BTN | data | u8 | 5
P_BTN0_A | data | u8 | 255
P_BTN0_B | data | u8 | 255
P_BTN0_C | data | u8 | 255
P_BTN1_A | data | u8 | 255
P_BTN1_B | data | u8 | 255
P_BTN1_C | data | u8 | 255
P_I2C_SCL | data | u8 | 255
P_I2C_SDA | data | u8 | 255
P_I2C_RST | data | u8 | 255
P_LCD_CS | data | u8 | 22
P_LCD_A0 | data | u8 | 23
P_LCD_RST | data | u8 | 21
P_IR_SIGNAL | data | u8 | 34
P_I2S_LRCK | data | u8 | 25
P_I2S_BCLK | data | u8 | 26
P_I2S_DATA | data | u8 | 27
P_ADC_KBD | data | u8 | 255
P_BACKLIGHT | data | u8 | 255
option_space | namespace
O_LCD_TYPE | data | u8 | 255
O_LCD_ROTA | data | u8 | 255
O_LCD_OUT | data | u32 | 0
O_DDMM_FLAG | data | u8 | 1
custom_ir_space | namespace
K_UP | data | string
K_LEFT | data | string
K_OK | data | string
K_RIGHT | data | string
K_DOWN | data | string
K_0 | data | string
K_1 | data | string
K_2 | data | string
K_3 | data | string
K_4 | data | string
K_5 | data | string
K_6 | data | string
K_7 | data | string
K_8 | data | string
K_9 | data | string
K_STAR | data | string
K_DIESE | data | string
K_INFO | data | string

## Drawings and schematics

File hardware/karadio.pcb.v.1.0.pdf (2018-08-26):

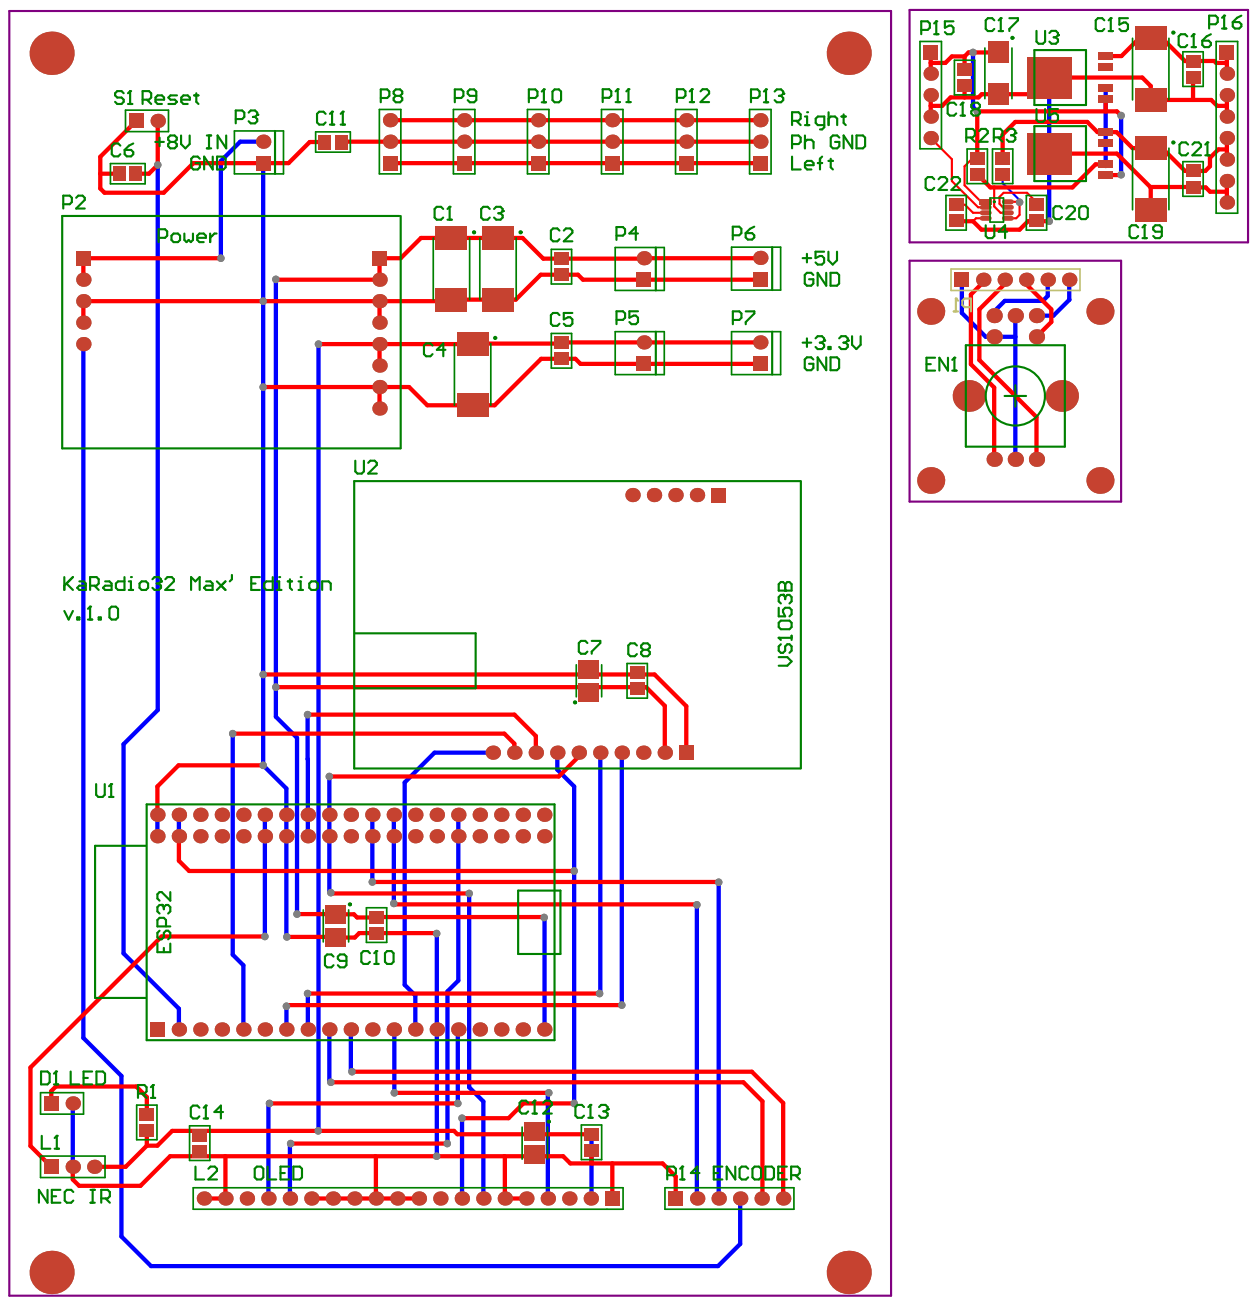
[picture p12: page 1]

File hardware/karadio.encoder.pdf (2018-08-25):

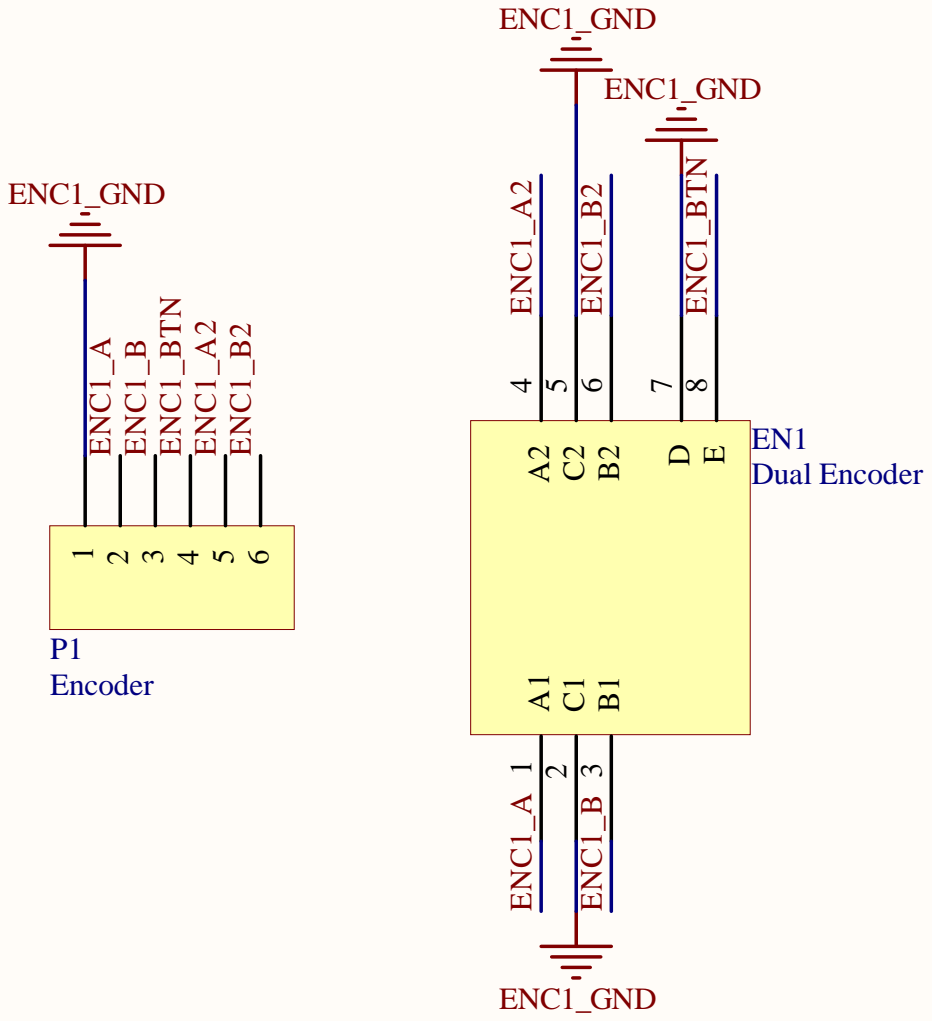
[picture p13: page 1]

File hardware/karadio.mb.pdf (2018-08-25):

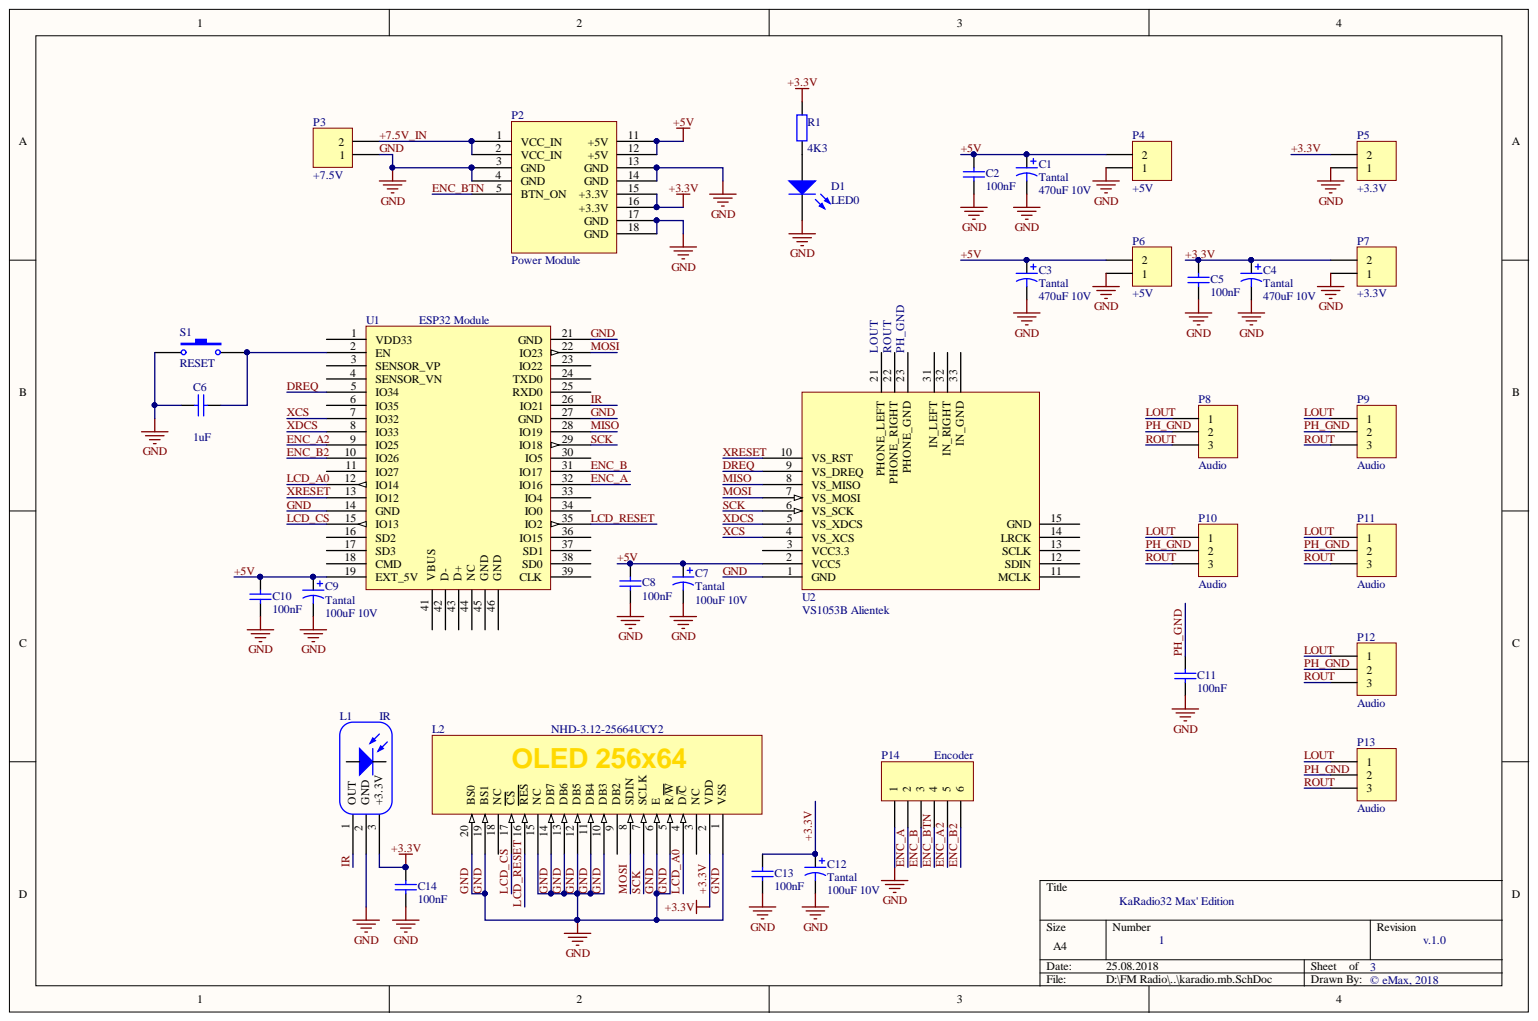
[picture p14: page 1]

VSS 1 VDD 2 NC 3 D/C 4 R/W 5 E 6 SCLK 7 SDIN 8 DB2 9 DB3 10 DB4 11 DB5 12 DB6 13 DB7 14 NC 15 RES 16 CS 17 NC 18 BS1 19 BS0 20

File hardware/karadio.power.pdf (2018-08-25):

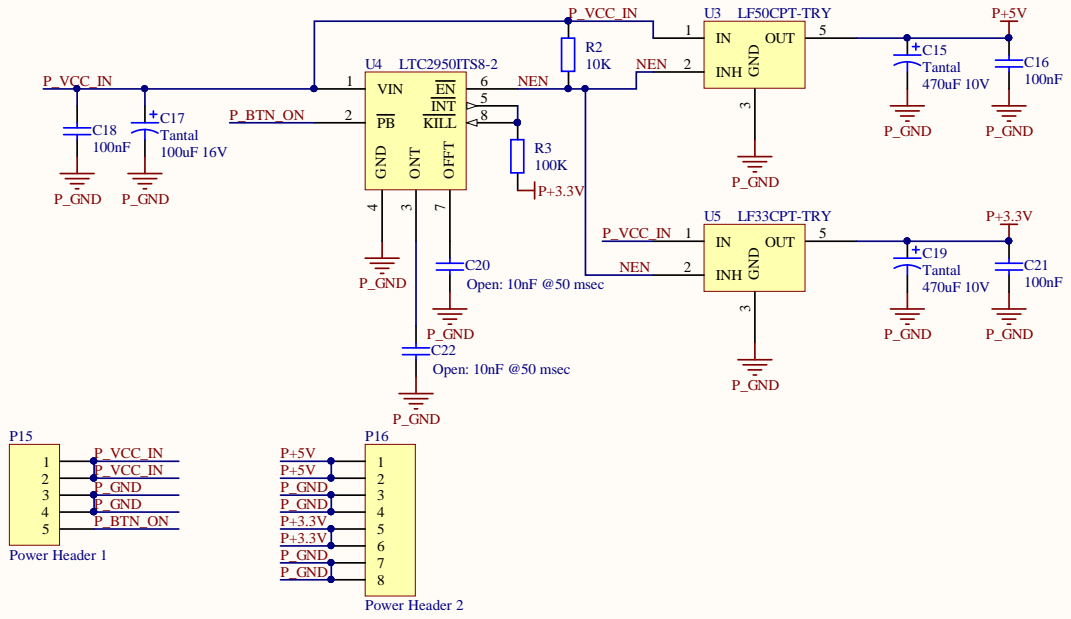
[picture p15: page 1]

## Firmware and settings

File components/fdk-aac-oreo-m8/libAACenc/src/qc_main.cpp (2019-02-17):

/* -----------------------------------------------------------------------------------------------------------
Software License for The Fraunhofer FDK AAC Codec Library for Android

© Copyright  1995 - 2015 Fraunhofer-Gesellschaft zur Förderung der angewandten Forschung e.V.
  All rights reserved.

 1.    INTRODUCTION
The Fraunhofer FDK AAC Codec Library for Android ("FDK AAC Codec") is software that implements
the MPEG Advanced Audio Coding ("AAC") encoding and decoding scheme for digital audio.
This FDK AAC Codec software is intended to be used on a wide variety of Android devices.

AAC's HE-AAC and HE-AAC v2 versions are regarded as today's most efficient general perceptual
audio codecs. AAC-ELD is considered the best-performing full-bandwidth communications codec by
independent studies and is widely deployed. AAC has been standardized by ISO and IEC as part
of the MPEG specifications.

Patent licenses for necessary patent claims for the FDK AAC Codec (including those of Fraunhofer)
may be obtained through Via Licensing (www.vialicensing.com) or through the respective patent owners
individually for the purpose of encoding or decoding bit streams in products that are compliant with
the ISO/IEC MPEG audio standards. Please note that most manufacturers of Android devices already license
these patent claims through Via Licensing or directly from the patent owners, and therefore FDK AAC Codec
software may already be covered under those patent licenses when it is used for those licensed purposes only.

Commercially-licensed AAC software libraries, including floating-point versions with enhanced sound quality,
are also available from Fraunhofer. Users are encouraged to check the Fraunhofer website for additional
applications information and documentation.

2.    COPYRIGHT LICENSE

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
You must retain the complete text of this software license in redistributions of the FDK AAC Codec or
your modifications thereto in source code form.

You must retain the complete text of this software license in the documentation and/or other materials
provided with redistributions of the FDK AAC Codec or your modifications thereto in binary form.
You must make available free of charge copies of the complete source code of the FDK AAC Codec and your
modifications thereto to recipients of copies in binary form.

The name of Fraunhofer may not be used to endorse or promote products derived from this library without
prior written permission.

You may not charge copyright license fees for anyone to use, copy or distribute the FDK AAC Codec
software or your modifications thereto.

Your modified versions of the FDK AAC Codec must carry prominent notices stating that you changed the software
and the date of any change. For modified versions of the FDK AAC Codec, the term
"Fraunhofer FDK AAC Codec Library for Android" must be replaced by the term
"Third-Party Modified Version of the Fraunhofer FDK AAC Codec Library for Android."

3.    NO PATENT LICENSE

NO EXPRESS OR IMPLIED LICENSES TO ANY PATENT CLAIMS, including without limitation the patents of Fraunhofer,
ARE GRANTED BY THIS SOFTWARE LICENSE. Fraunhofer provides no warranty of patent non-infringement with
respect to this software.

You may use this FDK AAC Codec software or modifications thereto only for purposes that are authorized
by appropriate patent licenses.

4.    DISCLAIMER

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
5.    CONTACT INFORMATION

Fraunhofer Institute for Integrated Circuits IIS
Attention: Audio and Multimedia Departments - FDK AAC LL
Am Wolfsmantel 33
91058 Erlangen, Germany

www.iis.fraunhofer.de/amm
amm-info@iis.fraunhofer.de
----------------------------------------------------------------------------------------------------------- */

/******************************** MPEG Audio Encoder **************************

   Initial author:       M. Werner
   contents/description: Quantizing & coding

******************************************************************************/

#include "qc_main.h"
#include "quantize.h"
#include "interface.h"
#include "adj_thr.h"
#include "sf_estim.h"
#include "bit_cnt.h"
#include "dyn_bits.h"
#include "channel_map.h"
#include "aacEnc_ram.h"

#include "genericStds.h"


typedef struct {
  QCDATA_BR_MODE bitrateMode;
  LONG vbrQualFactor;
} TAB_VBR_QUAL_FACTOR;

static const TAB_VBR_QUAL_FACTOR tableVbrQualFactor[] = {
  {QCDATA_BR_MODE_VBR_1, FL2FXCONST_DBL(0.160f)}, /* 32 kbps mono   AAC-LC + SBR + PS */
  {QCDATA_BR_MODE_VBR_2, FL2FXCONST_DBL(0.148f)}, /* 64 kbps stereo AAC-LC + SBR      */
  {QCDATA_BR_MODE_VBR_3, FL2FXCONST_DBL(0.135f)}, /* 80 - 96 kbps stereo AAC-LC       */
  {QCDATA_BR_MODE_VBR_4, FL2FXCONST_DBL(0.111f)}, /* 128 kbps stereo AAC-LC           */
  {QCDATA_BR_MODE_VBR_5, FL2FXCONST_DBL(0.070f)}  /* 192 kbps stereo AAC-LC           */
};

static INT isConstantBitrateMode(
        const QCDATA_BR_MODE bitrateMode
        )
{
  return ( ((bitrateMode==QCDATA_BR_MODE_CBR) || (bitrateMode==QCDATA_BR_MODE_SFR) || (bitrateMode==QCDATA_BR_MODE_FF)) ? 1 : 0 );
}



typedef enum{
    FRAME_LEN_BYTES_MODULO =  1,
    FRAME_LEN_BYTES_INT    =  2
}FRAME_LEN_RESULT_MODE;

/* forward declarations */

static INT FDKaacEnc_calcMaxValueInSfb(INT   sfbCnt,
                             INT   maxSfbPerGroup,
                             INT   sfbPerGroup,
                             INT  *RESTRICT sfbOffset,
                             SHORT *RESTRICT quantSpectrum,
                             UINT *RESTRICT maxValue);

static void FDKaacEnc_crashRecovery(INT               nChannels,
                          PSY_OUT_ELEMENT*  psyOutElement,
                          QC_OUT*           qcOut,
                          QC_OUT_ELEMENT   *qcElement,
                          INT               bitsToSave,
                          AUDIO_OBJECT_TYPE aot,
                          UINT              syntaxFlags,
                          SCHAR             epConfig);

static
AAC_ENCODER_ERROR FDKaacEnc_reduceBitConsumption(int*             iterations,
                                       const int        maxIterations,
                                       int              gainAdjustment,
                                       int*             chConstraintsFulfilled,
                                       int*             calculateQuant,
                                       int              nChannels,
                                       PSY_OUT_ELEMENT* psyOutElement,
                                       QC_OUT*          qcOut,
                                       QC_OUT_ELEMENT*  qcOutElement,
                                       ELEMENT_BITS*    elBits,
                                       AUDIO_OBJECT_TYPE  aot,
                                       UINT             syntaxFlags,
                                       SCHAR            epConfig);


void  FDKaacEnc_QCClose (QC_STATE  **phQCstate, QC_OUT **phQC);

/*****************************************************************************

    functionname: FDKaacEnc_calcFrameLen
    description:
    returns:
    input:
    output:

*****************************************************************************/
static INT FDKaacEnc_calcFrameLen(INT bitRate,
                        INT sampleRate,
                        INT granuleLength,
                        FRAME_LEN_RESULT_MODE mode)
{

   INT result;

   result = ((granuleLength)>>3)*(bitRate);

   switch(mode) {
     case FRAME_LEN_BYTES_MODULO:
         result %= sampleRate;
     break;
     case FRAME_LEN_BYTES_INT:
         result /= sampleRate;
     break;
   }
   return(result);
}

/*****************************************************************************

    functionname:FDKaacEnc_framePadding
    description: Calculates if padding is needed for actual frame
    returns:
    input:
    output:

*****************************************************************************/
static INT FDKaacEnc_framePadding(INT bitRate,
                        INT sampleRate,
                        INT granuleLength,
                        INT *paddingRest)
{
  INT paddingOn;
  INT difference;

  paddingOn = 0;

  difference = FDKaacEnc_calcFrameLen( bitRate,
                             sampleRate,
                             granuleLength,
                             FRAME_LEN_BYTES_MODULO );
  *paddingRest-=difference;

  if (*paddingRest <= 0 ) {
    paddingOn = 1;
    *paddingRest += sampleRate;
  }

  return( paddingOn );
}


/*********************************************************************************

         functionname: FDKaacEnc_QCOutNew
         description:
         return:

**********************************************************************************/
AAC_ENCODER_ERROR FDKaacEnc_QCOutNew(QC_OUT    **phQC,
                                     const INT   nElements,
                                     const INT   nChannels,
                                     const INT   nSubFrames
                                    ,UCHAR      *dynamic_RAM
                                    )
{
  AAC_ENCODER_ERROR ErrorStatus;
  int n, i;
  int elInc = 0, chInc = 0;

  for (n=0; n<nSubFrames; n++) {
    phQC[n] = GetRam_aacEnc_QCout(n);
    if (phQC[n] == NULL) {
      ErrorStatus = AAC_ENC_NO_MEMORY;
      goto QCOutNew_bail;
    }

    for (i=0; i<nChannels; i++) {
      phQC[n]->pQcOutChannels[i] = GetRam_aacEnc_QCchannel(chInc, dynamic_RAM);
      if ( phQC[n]->pQcOutChannels[i] == NULL
         )
      {
         ErrorStatus = AAC_ENC_NO_MEMORY;
         goto QCOutNew_bail;
      }
      chInc++;
    } /* nChannels */

    for (i=0; i<nElements; i++) {
      phQC[n]->qcElement[i]      = GetRam_aacEnc_QCelement(elInc);
      if (phQC[n]->qcElement[i] == NULL)
      {
        ErrorStatus = AAC_ENC_NO_MEMORY;
        goto QCOutNew_bail;
      }
      elInc++;
    } /* nElements */

  } /* nSubFrames */


  return AAC_ENC_OK;

QCOutNew_bail:
  return ErrorStatus;
}

/*********************************************************************************

         functionname: FDKaacEnc_QCOutInit
         description:
         return:

**********************************************************************************/
AAC_ENCODER_ERROR FDKaacEnc_QCOutInit(QC_OUT          *phQC[(1)],
                                      const INT        nSubFrames,
                                      const CHANNEL_MAPPING *cm)
{
  INT n,i,ch;

  for (n=0; n<nSubFrames; n++) {
    INT chInc = 0;
    for (i=0; i<cm->nElements; i++) {
      for (ch=0; ch<cm->elInfo[i].nChannelsInEl; ch++) {
        phQC[n]->qcElement[i]->qcOutChannel[ch] = phQC[n]->pQcOutChannels[chInc];
        chInc++;
      } /* chInEl */
    } /* nElements */
  } /* nSubFrames */

  return AAC_ENC_OK;
}

/*********************************************************************************

         functionname: FDKaacEnc_QCNew
         description:
         return:

**********************************************************************************/
AAC_ENCODER_ERROR FDKaacEnc_QCNew(QC_STATE  **phQC,
                                  INT         nElements
                                 ,UCHAR*      dynamic_RAM
           )
{
  AAC_ENCODER_ERROR ErrorStatus;
  int i;

  QC_STATE* hQC = GetRam_aacEnc_QCstate();
  *phQC = hQC;
  if (hQC == NULL) {
    ErrorStatus = AAC_ENC_NO_MEMORY;
    goto QCNew_bail;
  }

  if (FDKaacEnc_AdjThrNew(&hQC->hAdjThr, nElements)) {
    ErrorStatus = AAC_ENC_NO_MEMORY;
    goto QCNew_bail;
  }

  if (FDKaacEnc_BCNew(&(hQC->hBitCounter), dynamic_RAM)) {
    ErrorStatus = AAC_ENC_NO_MEMORY;
    goto QCNew_bail;
  }

  for (i=0; i<nElements; i++) {
    hQC->elementBits[i] = GetRam_aacEnc_ElementBits(i);
    if (hQC->elementBits[i] == NULL) {
      ErrorStatus = AAC_ENC_NO_MEMORY;
      goto QCNew_bail;
    }
  }

  return AAC_ENC_OK;

QCNew_bail:
  FDKaacEnc_QCClose(phQC, NULL);
  return ErrorStatus;
}

/*********************************************************************************

         functionname: FDKaacEnc_QCInit
         description:
         return:

**********************************************************************************/
AAC_ENCODER_ERROR FDKaacEnc_QCInit(QC_STATE *hQC,
                                   struct QC_INIT *init)
{
  int i;
  hQC->maxBitsPerFrame = init->maxBits;
  hQC->minBitsPerFrame = init->minBits;
  hQC->nElements       = init->channelMapping->nElements;
  hQC->bitResTotMax    = init->bitRes;
  hQC->bitResTot       = init->bitRes;
  hQC->maxBitFac       = init->maxBitFac;
  hQC->bitrateMode     = init->bitrateMode;
  hQC->invQuant        = init->invQuant;
  hQC->maxIterations   = init->maxIterations;

  if ( isConstantBitrateMode(hQC->bitrateMode) ) {
    INT bitresPerChannel = (hQC->bitResTotMax / init->channelMapping->nChannelsEff);
    /* 0: full bitreservoir, 1: reduced bitreservoir, 2: disabled bitreservoir */
    hQC->bitDistributionMode = (bitresPerChannel>BITRES_MIN_LD) ? 0 : (bitresPerChannel>0) ? 1 : 2;
  }
  else {
    hQC->bitDistributionMode = 0; /* full bitreservoir */
  }


  hQC->padding.paddingRest = init->padding.paddingRest;

  hQC->globHdrBits = init->staticBits; /* Bit overhead due to transport */

  FDKaacEnc_InitElementBits(hQC,
                            init->channelMapping,
                            init->bitrate,
                            (init->averageBits/init->nSubFrames) - hQC->globHdrBits,
                            hQC->maxBitsPerFrame/init->channelMapping->nChannelsEff);

  hQC->vbrQualFactor = FL2FXCONST_DBL(0.f);
  for (i=0; i<(int)(sizeof(tableVbrQualFactor)/sizeof(TAB_VBR_QUAL_FACTOR)); i++) {
    if (hQC->bitrateMode==tableVbrQualFactor[i].bitrateMode) {
      hQC->vbrQualFactor = (FIXP_DBL)tableVbrQualFactor[i].vbrQualFactor;
      break;
    }
  }

  if (init->channelMapping->nChannelsEff == 1 &&
     (init->bitrate / init->channelMapping->nChannelsEff) < 32000 &&
     init->advancedBitsToPe != 0
     )
  {
    hQC->dZoneQuantEnable = 1;
  } else {
    hQC->dZoneQuantEnable = 0;
  }

  FDKaacEnc_AdjThrInit(
        hQC->hAdjThr,
        init->meanPe,
        hQC->elementBits,                 /* or channelBitrates, was: channelBitrate */
        hQC->invQuant,
        init->channelMapping->nElements,
        init->channelMapping->nChannelsEff,
        init->sampleRate,                 /* output sample rate */
        init->advancedBitsToPe,           /* if set, calc bits2PE factor depending on samplerate */
        hQC->vbrQualFactor,
        hQC->dZoneQuantEnable
        );

  return AAC_ENC_OK;
}



/*********************************************************************************

         functionname: FDKaacEnc_QCMainPrepare
         description:
         return:

**********************************************************************************/
AAC_ENCODER_ERROR FDKaacEnc_QCMainPrepare(ELEMENT_INFO              *elInfo,
                                          ATS_ELEMENT* RESTRICT      adjThrStateElement,
                                          PSY_OUT_ELEMENT* RESTRICT  psyOutElement,
                                          QC_OUT_ELEMENT* RESTRICT   qcOutElement,
                                          AUDIO_OBJECT_TYPE          aot,
                                          UINT                       syntaxFlags,
                                          SCHAR                      epConfig
                                         )
{
  AAC_ENCODER_ERROR ErrorStatus = AAC_ENC_OK;
  INT  nChannels = elInfo->nChannelsInEl;

  PSY_OUT_CHANNEL** RESTRICT psyOutChannel = psyOutElement->psyOutChannel;    /* may be modified in-place */

  FDKaacEnc_CalcFormFactor(qcOutElement->qcOutChannel, psyOutChannel, nChannels);

  /* prepare and calculate PE without reduction */
  FDKaacEnc_peCalculation(&qcOutElement->peData, psyOutChannel, qcOutElement->qcOutChannel, &psyOutElement->toolsInfo, adjThrStateElement, nChannels);

  ErrorStatus = FDKaacEnc_ChannelElementWrite( NULL, elInfo, NULL,
                                               psyOutElement,
                                               psyOutElement->psyOutChannel,
                                               syntaxFlags,
                                               aot,
                                               epConfig,
                                              &qcOutElement->staticBitsUsed,
                                               0 );

  return ErrorStatus;
}

/*********************************************************************************

         functionname: FDKaacEnc_AdjustBitrate
         description:  adjusts framelength via padding on a frame to frame basis,
                       to achieve a bitrate that demands a non byte aligned
                       framelength
         return:       errorcode

**********************************************************************************/
AAC_ENCODER_ERROR FDKaacEnc_AdjustBitrate(QC_STATE        *RESTRICT hQC,
                                          CHANNEL_MAPPING *RESTRICT cm,
                                          INT             *avgTotalBits,
                                          INT              bitRate,       /* total bitrate */
                                          INT              sampleRate,    /* output sampling rate */
                                          INT              granuleLength) /* frame length */
{
  INT paddingOn;
  INT frameLen;

  /* Do we need an extra padding byte? */
  paddingOn = FDKaacEnc_framePadding(bitRate,
                           sampleRate,
                           granuleLength,
                          &hQC->padding.paddingRest);

  frameLen = paddingOn + FDKaacEnc_calcFrameLen(bitRate,
                                      sampleRate,
                                      granuleLength,
                                      FRAME_LEN_BYTES_INT);

  *avgTotalBits = frameLen<<3;

  return AAC_ENC_OK;
}

static AAC_ENCODER_ERROR FDKaacEnc_distributeElementDynBits(QC_STATE*         hQC,
                                                  QC_OUT_ELEMENT*   qcElement[(8)],
                                                  CHANNEL_MAPPING*  cm,
                                                  INT               codeBits)
{

  INT i, firstEl = cm->nElements-1;
  INT totalBits = 0;

  for (i=(cm->nElements-1); i>=0; i--) {
    if ((cm->elInfo[i].elType == ID_SCE) || (cm->elInfo[i].elType == ID_CPE) ||
        (cm->elInfo[i].elType == ID_LFE))
    {
      qcElement[i]->grantedDynBits =  (INT)fMult(hQC->elementBits[i]->relativeBitsEl, (FIXP_DBL)codeBits);
      totalBits += qcElement[i]->grantedDynBits;
      firstEl = i;
    }
  }
  qcElement[firstEl]->grantedDynBits += codeBits - totalBits;

  return AAC_ENC_OK;
}

/**
 * \brief  Verify whether minBitsPerFrame criterion can be satisfied.
 *
 * This function evaluates the bit consumption only if minBitsPerFrame parameter is not 0.
 * In hyperframing mode the difference between grantedDynBits and usedDynBits of all sub frames
 * results the number of fillbits to be written.
 * This bits can be distrubitued in superframe to reach minBitsPerFrame bit consumption in single AU's.
 * The return value denotes if enough desired fill bits are available to achieve minBitsPerFrame in all frames.
 * This check can only be used within superframes.
 *
 * \param qcOut            Pointer to coding data struct.
 * \param minBitsPerFrame  Minimal number of bits to be consumed in each frame.
 * \param nSubFrames       Number of frames in superframe
 *
 * \return
 *          - 1: all fine
 *          - 0: criterion not fulfilled
 */
static int checkMinFrameBitsDemand(
        QC_OUT**                  qcOut,
        const INT                 minBitsPerFrame,
        const INT                 nSubFrames
        )
{
  int result = 1; /* all fine*/
  return result;
}

////////////////////////////////////////////////////////////////////////////////////////////////////////////////////////////////

////////////////////////////////////////////////////////////////////////////////////////////////////////////////////////////////
/*********************************************************************************

         functionname: FDKaacEnc_getMinimalStaticBitdemand
         description:  calculate minmal size of static bits by reduction ,
                       to zero spectrum and deactivating tns and MS
         return:       number of static bits

**********************************************************************************/
static int FDKaacEnc_getMinimalStaticBitdemand(CHANNEL_MAPPING*     cm,
                                               PSY_OUT**            psyOut)
{
  AUDIO_OBJECT_TYPE aot = AOT_AAC_LC;
  UINT  syntaxFlags = 0;
  SCHAR epConfig = -1;
  int i, bitcount = 0;

  for (i=0; i<cm->nElements; i++) {
      ELEMENT_INFO elInfo = cm->elInfo[i];

      if ( (elInfo.elType == ID_SCE)
        || (elInfo.elType == ID_CPE)
        || (elInfo.elType == ID_LFE) )
      {
        INT minElBits = 0;

        FDKaacEnc_ChannelElementWrite( NULL, &elInfo, NULL,
                                       psyOut[0]->psyOutElement[i],
                                       psyOut[0]->psyOutElement[i]->psyOutChannel,
                                       syntaxFlags,
                                       aot,
                                       epConfig,
                                      &minElBits,
                                       1 );
        bitcount += minElBits;
      }
  }

  return bitcount;
}

////////////////////////////////////////////////////////////////////////////////////////////////////////////////////////////////
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

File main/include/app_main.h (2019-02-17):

/*
 * app_main.h
 *
 *  Created on: 13.03.2017
 *      Author: michaelboeckling
 *  Modified on 15.09.2017 for KaraDio32
 *		jp Cocatrix
 * Copyright (c) 2017, jp Cocatrix
 * All rights reserved.
 * 
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
 * * Neither the name of the copyright holder nor the names of its
 *   contributors may be used to endorse or promote products derived from
 *   this software without specific prior written permission.
 * 
 * THIS SOFTWARE IS PROVIDED BY THE COPYRIGHT HOLDERS AND CONTRIBUTORS "AS IS"
 * AND ANY EXPRESS OR IMPLIED WARRANTIES, INCLUDING, BUT NOT LIMITED TO, THE
 * IMPLIED WARRANTIES OF MERCHANTABILITY AND FITNESS FOR A PARTICULAR PURPOSE ARE
 * DISCLAIMED. IN NO EVENT SHALL THE COPYRIGHT HOLDER OR CONTRIBUTORS BE LIABLE
 * FOR ANY DIRECT, INDIRECT, INCIDENTAL, SPECIAL, EXEMPLARY, OR CONSEQUENTIAL
 * DAMAGES (INCLUDING, BUT NOT LIMITED TO, PROCUREMENT OF SUBSTITUTE GOODS OR
 * SERVICES; LOSS OF USE, DATA, OR PROFITS; OR BUSINESS INTERRUPTION) HOWEVER
 * CAUSED AND ON ANY THEORY OF LIABILITY, WHETHER IN CONTRACT, STRICT LIABILITY,
 * OR TORT (INCLUDING NEGLIGENCE OR OTHERWISE) ARISING IN ANY WAY OUT OF THE USE
 * OF THIS SOFTWARE, EVEN IF ADVISED OF THE POSSIBILITY OF SUCH DAMAGE.
 */

#ifndef MAIN_INCLUDE_APP_MAIN_H_
#define MAIN_INCLUDE_APP_MAIN_H_
#include "audio_renderer.h"
#include "driver/timer.h"

#define TIMER_DIVIDER 16 	//5000000Hz 5MHz
#define TIMER_DIVIDER1MS TIMER_BASE_CLK/10000 //10000Hz 
#define TIMER_DIVIDER1mS 8 //10000000Hz 10MHz

#define TIMERVALUE(x) (x*5000000 )
#define TIMERVALUE1MS(x) (x*10) 
#define TIMERVALUE1mS(x) (x*10000 )
#define TIMERGROUP TIMER_GROUP_0 
#define TIMERGROUP1MS TIMER_GROUP_1
#define TIMERGROUP1mS TIMER_GROUP_1
#define msTimer	TIMER_0
#define microsTimer	TIMER_1
#define sleepTimer  TIMER_0
#define wakeTimer TIMER_1

//extern os_timer_t sleepTimer;
extern uint32_t sleepDelay;
//extern os_timer_t wakeTimer;
extern uint32_t wakeDelay;

// event for timers and encoder
#define TIMER_SLEEP   0   
#define TIMER_WAKE    1 
#define TIMER_1MS	2
#define TIMER_1mS	3

/* // Tasks priority
#define PRIO_MAD 		7
#define PRIO_VS1053 	4
#define PRIO_RMT		7
#define PRIO_UART		2
#define PRIO_CLIENT		4
#define PRIO_SERVER		3
#define PRIO_ADDON		5
#define PRIO_LCD		6
#define PRIO_SUBSERV	3
#define PRIO_TIMER		1
#define PRIO_OTA		10

// CPU for task
#define CPU_MAD			0  // internal decoder and vs1053
#define CPU_RMT			0
#define CPU_UART		1
#define CPU_CLIENT		1
#define CPU_SERVER		0
#define CPU_ADDON		1
#define CPU_LCD			1
#define CPU_SUBSERV		0
#define CPU_TIMER		1
 */


// Tasks priority
#define PRIO_MAD 		5
#define PRIO_VS1053 	4
#define PRIO_RMT		5
#define PRIO_UART		3
#define PRIO_CLIENT		6
#define PRIO_SERVER		5
#define PRIO_ADDON		6
#define PRIO_LCD		4
#define PRIO_SUBSERV	5
#define PRIO_TIMER		11
#define PRIO_OTA		10

// CPU for task
#define CPU_MAD			1  // internal decoder and vs1053
#define CPU_RMT			1
#define CPU_UART		0
#define CPU_CLIENT		1
#define CPU_SERVER		0
#define CPU_ADDON		1
#define CPU_LCD			0
#define CPU_SUBSERV		1
#define CPU_TIMER		0

#define TEMPO_SAVE_VOL	10000

typedef struct {
    int type;               /*!< event type */
    int i1;                 /*!< TIMER_xxx timer group */
    int i2;                 /*!< TIMER_xxx timer number */
} queue_event_t;

output_mode_t get_audio_output_mode() ;

uint8_t getIvol();
void setIvol( uint8_t vol);
bool bigSram();

void sleepCallback(void *pArg);
void wakeCallback(void *pArg);
void startSleep(uint32_t delay);
void stopSleep();
void startWake(uint32_t delay);
void stopWake();
void noInterrupt1Ms();
void interrupt1Ms();
#define noInterrupts noInterrupt1Ms
#define interrupts interrupt1Ms
//void noInterrupts();
//void interrupts();
char* getIp();


#endif /* MAIN_INCLUDE_APP_MAIN_H_ */

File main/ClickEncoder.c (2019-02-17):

// ----------------------------------------------------------------------------
// Rotary Encoder Driver with enc->acceleration
// Supports Click, DoubleClick, Long Click
//
// (c) 2010 karl@pitrich.com
// (c) 2014 karl@pitrich.com
// 
// Timer-based rotary encoder logic by Peter Dannegger
// http://www.mikrocontroller.net/articles/Drehgeber
// ----------------------------------------------------------------------------
#define LOG_LOCAL_LEVEL ESP_LOG_VERBOSE
#include <stddef.h>
#include <string.h>
#include <stdio.h>
#include <sys/time.h>
#include "ClickEncoder.h"
#include "app_main.h"
#include "freertos/FreeRTOS.h"
#include "freertos/task.h"

// ----------------------------------------------------------------------------
// enc->acceleration configuration (for 1000Hz calls to ::service())
//
#define ENC_ACCEL_TOP    3072    // max. acceleration:  (val >> 5)
#define ENC_ACCEL_INC    80
#define ENC_ACCEL_DEC 	 2

// ----------------------------------------------------------------------------
/*
  int8_t enc->pinA;
  int8_t enc->pinB;
  int8_t enc->pinBTN;
  bool enc->pinsActive;
  volatile int16_t enc->delta;
  volatile int16_t enc->last;
  volatile uint8_t enc->steps;
  volatile uint16_t enc->acceleration;
  bool enc->accelerationEnabled;
  volatile enc->button enc->button;
  bool enc->doubleClickEnabled;
  bool buttonHeldEnabled;
  bool enc->buttonOnPinZeroEnabled = false;
  uint16_t enc->keyDownTicks = 0;
  uint16_t enc->doubleClickTicks = 0;
  uint16_t buttonHoldTime = BTN_HOLDTIME;
  uint16_t buttonDoubleClickTime = BTN_DOUBLECLICKTIME;
  unsigned long enc->lastButtonCheck = 0;
*/


#define TAG "ClickEncoder"

  
// ----------------------------------------------------------------------------

bool getpinsActive(Encoder_t *enc) {return enc->pinsActive;}

Encoder_t* ClickEncoderInit(int8_t A, int8_t B, int8_t BTN, bool initHalfStep)
{
	
	Encoder_t* enc = malloc(sizeof(Encoder_t));
	enc->pinA = A; enc->pinB = B;
	if (BTN == -1) enc->pinBTN = 0;
		else enc->pinBTN = BTN;
	enc->pinsActive = LOW; enc->delta = 0; enc->last = 0; enc->steps = 4; 
	enc->accelerationEnabled = true; enc->button = Open;
	enc->doubleClickEnabled = true; enc->buttonHeldEnabled = true;
	enc->accel_inc = ENC_ACCEL_INC;

	if (initHalfStep) 
	{
		enc->steps = 2;
		enc->accel_inc = ENC_ACCEL_INC /2;
	}
	
	enc->keyDownTicks = 0;
	enc->doubleClickTicks = 0;
	enc->lastButtonCheck = 0;
	enc->acceleration = 0;
	
	gpio_config_t gpio_conf;
	gpio_conf.mode = GPIO_MODE_INPUT;
	gpio_conf.pull_up_en =  (enc->pinsActive == LOW) ?GPIO_PULLUP_ENABLE : GPIO_PULLUP_DISABLE;
	gpio_conf.pull_down_en = (enc->pinsActive == LOW) ?GPIO_PULLDOWN_DISABLE : GPIO_PULLDOWN_ENABLE;
	gpio_conf.intr_type = GPIO_INTR_DISABLE;
	
  if (enc->pinA > 0) 
  {
	gpio_conf.pin_bit_mask = ((uint64_t)(((uint64_t)1)<<enc->pinA));
	ESP_ERROR_CHECK(gpio_config(&gpio_conf));
  }
  if (enc->pinB > 0) 
  {
	gpio_conf.pin_bit_mask = ((uint64_t)(((uint64_t)1)<<enc->pinB));
	ESP_ERROR_CHECK(gpio_config(&gpio_conf));
  }
  if (enc->pinBTN > 0) 
  {
	gpio_conf.pin_bit_mask = ((uint64_t)(((uint64_t)1)<<enc->pinBTN));
	ESP_ERROR_CHECK(gpio_config(&gpio_conf));
  }

  
  if (digitalRead(enc->pinA) == enc->pinsActive) {
    enc->last = 3;
  }

  if (digitalRead(enc->pinB) == enc->pinsActive) {
    enc->last ^=1;
  }
  return enc;
}

// number of steps per notch
void setHalfStep(Encoder_t *enc, bool value)
{
	if (value) enc->steps = 2;	
	else enc->steps = 4;	
}
bool getHalfStep(Encoder_t *enc)
{
//	return enc->halfStep ;	
   if (enc->steps == 2) return true;
   return false;
}
// ----------------------------------------------------------------------------
// call this every 1 millisecond via timer ISR
//
//void (*serviceEncoder)() = NULL;
IRAM_ATTR void service(Encoder_t *enc)
{
  bool moved = false;
  
  if (enc->pinA >= 0 && enc->pinB >= 0) {
  if (enc->accelerationEnabled) { // decelerate every tick
    enc->acceleration -= ENC_ACCEL_DEC;
    if (enc->acceleration & 0x8000) { // handle overflow of MSB is set
      enc->acceleration = 0;
    }
  }

	int8_t curr = 0; 
	if (digitalRead(enc->pinA) == enc->pinsActive) {
		curr = 3;
	}

	if (digitalRead(enc->pinB) == enc->pinsActive) {
		curr ^= 1;
	}
  
	int8_t diff = enc->last - curr;
  
	if (diff & 1) {            // bit 0 = step
		enc->last = curr;
		enc->delta += (diff & 2) - 1; // bit 1 = direction (+/-)
		moved = true;    
	}

  if (enc->accelerationEnabled && moved) {
    // increment accelerator if encoder has been moved
    if (enc->acceleration <= (ENC_ACCEL_TOP - enc->accel_inc)) {
      enc->acceleration += enc->accel_inc ;
    }
  }
}
  // handle enc->button
  //
  unsigned long currentMillis = xTaskGetTickCount()* portTICK_PERIOD_MS;
  if (currentMillis < enc->lastButtonCheck) enc->lastButtonCheck = 0;        // Handle case when millis() wraps back around to zero
  if ((enc->pinBTN > 0 )        // check enc->button only, if a pin has been provided
      && ((currentMillis - enc->lastButtonCheck) >= ENC_BUTTONINTERVAL))            // checking enc->button is sufficient every 10-30ms
  { 
    enc->lastButtonCheck = currentMillis;

    bool pinRead = getPinState(enc);
    
    if (pinRead == enc->pinsActive) { // key is down
      enc->keyDownTicks++;
      if ((enc->keyDownTicks > (BTN_HOLDTIME / ENC_BUTTONINTERVAL)) && (enc->buttonHeldEnabled)) {
        enc->button = Held;
      }
    }

    if (pinRead == !enc->pinsActive) { // key is now up
      if (enc->keyDownTicks > 1) {               //Make sure key was down through 1 complete tick to prevent random transients from registering as click
        if (enc->button == Held) {
          enc->button = Released;
          enc->doubleClickTicks = 0;
        }
        else {
          #define ENC_SINGLECLICKONLY 1
          if (enc->doubleClickTicks > ENC_SINGLECLICKONLY) {   // prevent trigger in single click mode
            if (enc->doubleClickTicks < (BTN_DOUBLECLICKTIME / ENC_BUTTONINTERVAL)) {
              enc->button = DoubleClicked;
              enc->doubleClickTicks = 0;
            }
          }
          else {
            enc->doubleClickTicks = (enc->doubleClickEnabled) ? (BTN_DOUBLECLICKTIME / ENC_BUTTONINTERVAL) : ENC_SINGLECLICKONLY;
          }
        }
      }

      enc->keyDownTicks = 0;
    }
  
    if (enc->doubleClickTicks > 0) {
      enc->doubleClickTicks--;
      if (enc->doubleClickTicks == 0) {
        enc->button = Clicked;
      }
    }
  }
}

// ----------------------------------------------------------------------------
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

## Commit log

2018-08-19 Schematic added
2018-08-25 Added PCB Gerber files, Schematic updated to v.1.0
    [BOM.ods]
2018-08-26 BOM Updated
    [BOM.ods]
2018-08-26 BOM updated 2
    [BOM.ods]
2018-08-26 BOM Updated 3
    [BOM.ods]
2018-08-26 PCB view added, BOM updated
    [BOM.ods]
2018-08-26 PCB View updated
2018-08-26 BOM LDO Fixed
    [BOM.ods]
2018-08-29 Some 3D printed details added
    [IR.TSO4438.stl, IR.stl, Knob1.2.stl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]
2018-09-01 Double Encoder for specific hardware
2018-09-02 Fix Scrolling of multibyte UTF-8 symbols
    [addonu8g2.c]
2018-09-09 Various Displays SPI clocks
2018-11-10 partition hex radix
    [max_ed_part.csv]
2018-11-11 255 for unused gpio
    [max_ed_part.csv]
2018-11-11 changes 4
    [max_ed_part1.csv]
2018-11-11 New in gpio part
    [max_ed_part1.csv]
2018-11-12 Restore useful mods
    1. u8g2 SPI speed depends from controller;
    2. Erase &amp; => & sequence from display
2019-02-17 update gpio
    [max_edition.csv]
